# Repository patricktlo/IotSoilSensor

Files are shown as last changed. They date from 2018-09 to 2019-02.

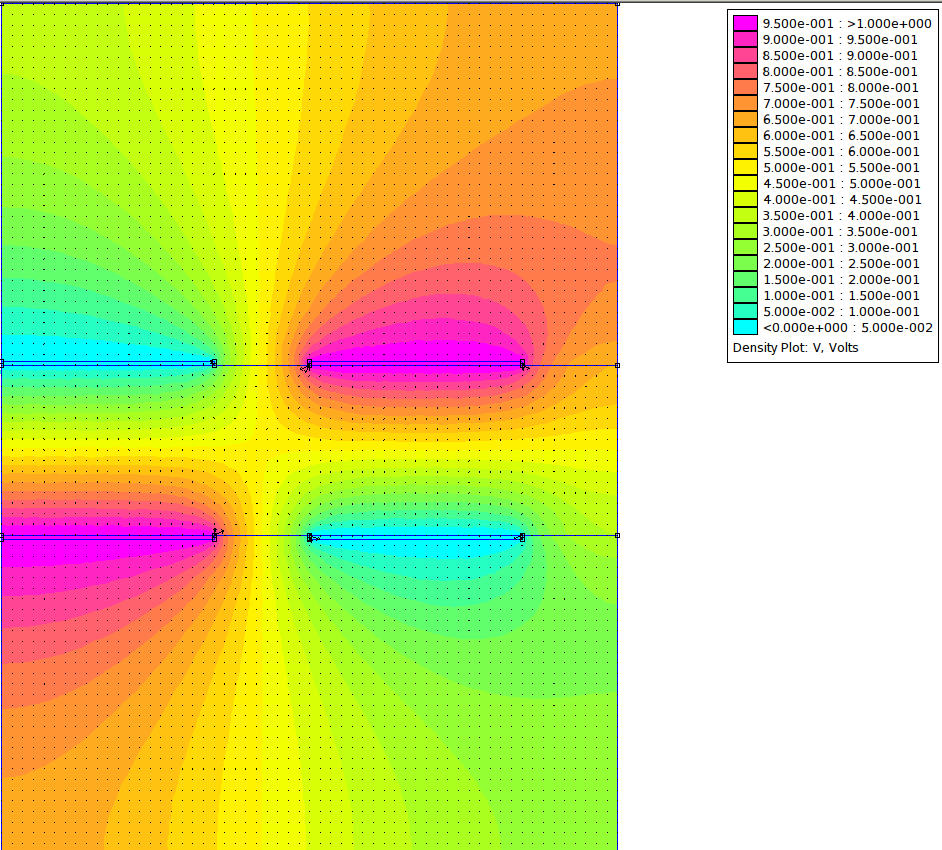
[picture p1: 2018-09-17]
1_Simulations/Moisture sensor/Simulation/FEMM Files/Images/w20_d09_air.png

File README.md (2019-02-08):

# IotSoilSensor

## This document is under construction!

This project aims to create a cheap LoRa-connected device to measure soil moisture using an embedded capacitive sensor. It also has a temperature sensor (NTC) and an air humidity sensor (HR202).

This project also contains a small simple gateway for LoRa using a LoRa module, a microcontroller and a Raspberry Pi.

## Soil moisture sensor

For the geometry of the sensor I chose a fringing field capacitive sensor because it is well documented and used in academic papers, it was also easy to design it in KiCAD, and easy to simulate in FEMM.

To measure the capacitance a simple RC circuit is used, where R is chosen to achieve a good resolution and measuring range. A comparator (which is inside the STM32L051 microcontroller) is connected to the output of the RC circuit, a simple resistive divider giving Vcc/2 is connected to the other pin of the comparator. 

A square wave is applied to the RC circuit, once the comparator changes state, the code of the MCU gets the value of the timer (the same one used for the square wave generations), with this value it is possible to measure the RC constant and hence the capacitive value. This circuit works quite well, before testing the capacitive sensor with it I tried it with capacitors and the results were really close to the nominal capacitive values ([data here](1_Simulations/Moisture%20sensor/Calibration/test_caps.ods))

### Soil moisture sensor calibration

The gravimetric analysis was used to calibrate our sensor, data can be found [here](1_Simulations/Moisture%20sensor/Calibration/test_gravi.ods). 

## Temperature sensor
The temperature sensor is an NTC thermistor because it's simple, cheap and doesn't depend on battery voltage (like DHT11 and others). The circuit is a simple resistor divider, where the value of the other resistor was chosen by finding the inflection point (using a double derivative, more information on the [HR202 sensor python notebook](1_Simulations/HR202/RH Simulation.ipynb), where I developed the math), you can find the math and some cool graphs on the [NTC sensor python notebook](1_Simulations/NTC/Simulation.ipynb). 

### Temperature sensor calibration
I used the beta-equation for the NTC, [look here for more info](1_Simulations/NTC/Simulation.ipynb).
      
The value of beta was given in the datasheet but I wanted to get a closer value so I calibrated it, see more details [in this spreadsheet](1_Simulations/NTC/NTC_calibration.ods).

## Air humidity sensor
The air humidity sensor was a tough one, it would've been pretty simple and straightforward to use a DHT11, but it would stop working when battery levels got to 3V (so pretty soon considering I'm using two AA batteries). So, I chose the HR202, there's not much about it but it's basically a resistive sensor, the RH value changes with temperature and you have to apply AC to it.

In order to provide AC voltage, I polarized the output at Vcc/2, using a resistor divider (look into the [LTSpice file](1_Simulations/HR202/hr202.asc) or the [KiCAD schematic](2_PCB/schematic.pdf) for more. The value of the resistor in this resistor divider is crucial because its value (or more precisely, the equivalent value of the two) define the output characteristics. To find the value of the resistors the inflex point was used (more info on the [HR202 sensor python notebook](1_Simulations/HR202/RH%20Simulation.ipynb)).

Also, just a quick note, since the input voltage is a square wave controlled by a timer, and we want to gather data from the ADC in sync with the square wave, it is needed to fire the ADC conversion with a timer as well.

### Air humidity calibration

It is difficult to calibrate this sensor, I found that the values in the datasheet weren't close to my results (although it could be some error in the circuit, I later found in another datasheet a somewhat different circuit which could work better). In order to get a fixed relative air humidity, I put the sensor inside a sealed container with a bottle cap of salt and water, that way after a few hours it gets to 75%.
I had an air humidity sensor so I could also use it as a reference. Even though the HR202 wasn't giving out exactly what was written on the datasheet, one could see the output voltage had a correlation with the humidity, so I got two known points, the 75% from the salt-water solution and the ambient RH from the other sensor, and fitted my sensor values to this line. It's far from perfect but it does give an idea of the RH.

## Battery

## LoRa

## STM32L051

## PCB

## Gateway
### Database

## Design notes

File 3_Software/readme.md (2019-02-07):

# Software

Two sub-folders are present here, one for the device itself, and one for the Gateway.

## Device

Code for the STM32L051 microcontroller is here, I used Atollic as my IDE (its free!) but you can use anything you like.

## Gateway

The gateway is separated into two components, a LoRa module connected to a STM32F103 MCU, and this one connected via UART to a rapsberry pi.

The sole purpose of the STM32 is to get LoRa messages, decode them and send them to the Raspberry Pi via UART, the RPi will then convert the ADC values into "real" values, and store them into an SQLite database. The RPi also has PHPLiteAdmin into it!

For future versions one might take the STM32 out of the gateway completely, but I was short in time!

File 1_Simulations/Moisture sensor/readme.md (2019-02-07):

# Moisture sensor simulation and calibration

I chose a fringing capacitance sensor because that's what was used in the articles I read and proved itself very efficient!

Here we have all files related to the simulation and calibration of the moisture sensor!

For simulation look at the simulation folder where you'll find LTSpice files for electrical simulations, FEMM files for estimating capacitance of the sensor (summary in the fringe_parameter_study.ods) and some timer-related calculations on the python notebook!

For calibration, test_caps.ods shows our circuit tested with capacitors, and it works extremely well!
On test_gravi.ods there's the gravimetric analysis I conducted in order to find out the equation which relates timer counts to humidity percentage.

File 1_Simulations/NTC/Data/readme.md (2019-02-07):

# Experimental values 

These are some tests I executed in order to estimate the noise.

The values are the ones given directly by the 12-bit ADC. If I remember correctly, sample time is 1 second.

ADC values are on the first column.

For the naming conventions:

avgX: means that the ADC used X-sample oversampling (executed at the hardware level).

capX: is the value of the capacitor connected to the ADC input.

gpio: means the power supply of the circuit was one GPIO pin of the microcontroller.

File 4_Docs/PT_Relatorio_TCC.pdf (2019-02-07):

MINISTERIO DA EDUCAÇ ´ | AÕ
UNIVERSIDADE FEDERAL DO PARANÁ

PATRICK THIERRY LORUSSO EL OMAIRI

DESENVOLVIMENTO DE UMA SOLUÇ AO INTERNET DAS COISAS ˜ PARA MEDIDA REMOTA DE TEMPERATURA, UMIDADE DO AR E DO SOLO COM BAIXO CUSTO E BAIXO CONSUMO DE ENERGIA

CURITIBA

2018

PATRICK THIERRY LORUSSO EL OMAIRI

DESENVOLVIMENTO DE UMA SOLUÇ AO INTERNET DAS COISAS ˜ PARA MEDIDA REMOTA DE TEMPERATURA, UMIDADE DO AR E DO SOLO COM BAIXO CUSTO E BAIXO CONSUMO DE ENERGIA

Trabalho | de | conclusao | de | curso ˜
apresentado | como | requisito | parcial
para a obtençao do grau de engenheiro ˜ eletricista, no programa de graduaçaõ em engenharia eletrica da Universidade ´ Federal do Parana. ´
Orientador: Prof. Dr. Marlio Jos ´ | e do Couto ´
Bonfim

CURITIBA

2018

AGRADECIMENTOS

Agradeço o Professor Marlio Jos ´ | e do Couto Bonfim pela orientaç ´ | ao durante todo esse ˜
trabalho que foi crucial para o sucesso do mesmo. Gostaria de agradecer tambem´ toda a minha família, minha namorada e meus amigos que tanto me apoiaram em todos os momentos.

RESUMO

Considerando a grande extensao territorial do Brasil e suas vastas lavouras, ˜ | é
imprescindível o uso de tecnologia na agricultura para aumento da produtividade. Dispositivos IoT e o avanço da agricultura 4.0 podem auxiliar imensamente nesta
tarefa. Neste contexto, esse trabalho propoe o desenvolvimento de uma soluç ˜ | ao de ˜
mediçao remota da temperatura, umidade relativa do ar e umidade do solo, com ˜
transmissao por uma rede ˜ | IoT LoRa de baixo consumo, com a intençao de obter uma ˜
soluçao com uma bateria de longa duraç ˜ | ao e baixo custo, com o uso de um ˜
microcontrolador STM32 e os sensores integrados na placa. O escopo deste trabalho
vai desde o desenvolvimento teorico desta soluç ´ | ao at ˜ | e um prot ´ | otipo para ser testado ´
em ambientes controlados. Este projeto sera open source e open hardware, para que
fazendeiros e pesquisadores da area possam utiliz ´ | a-lo livremente. | O prot ´ | otipo ´
desenvolvido tem uma autonomia de aproximadamente um ano e quatro meses com duas pilhas AA alcalinas, com um preço de 25 reais cada sensor. O prototipo mostra ´ que e poss ´ ível o desenvolvimento de um dispositivo como foi proposto.

Palavras Chave Agricultura 4.0, IoT, umidade do solo, LoRa.

ABSTRACT

Considering Brazil has a vast territory and a big part of it is being used for agriculture, it is crucial to use technology to augment productivity. IoT devices and agriculture 4.0 can help immensely in this task. In this context, this project seeks to develop a solution for the remote monitoring of temperature, soil moisture, and air humidity, using a LoRa network for transmission and an STM32L051 microcontroller aiming for a long battery life and low cost of the device. This project goes from the theory until the prototype, and it is open source and open hardware so that people can use this project in the future freely. The prototype has a battery life of about one year and four months, costing US$ 6.65 a piece. The prototype shows it’s possible to develop a product based on what was proposed.

Key-words: Agriculture 4.0, IoT, soil moisture, LoRa

LISTA DE FIGURAS

2.1 Curva característica de um resistor NTC. Fonte: O Autor (2018) | 11
2.2 Disposiçao dos condutores no sensor capacitivo. Fonte: DEAN et al. ˜
(2012) | | 13
2.3 Visao transversal dos condutores no sensor capacitivo. | Fonte: ˜
GOSWAMI, MONTAZER e SARMA (2018) | | 13
2.4 Divisor de tensao com um sensor. Fonte: O Autor (2018) | | 14 ˜

4.1 Esquematico do circuito de condicionamento feito no KiCAD. Fonte: O ´
Autor (2018) | | 17
4.2 Simulaçao da resposta do sensor aproximado com uma funç ˜ | ao de ˜
primeiro e terceiro grau e erros associados, a potencia dissipada no ˆ
NTC e o aumento da temperatura devido a essa potencia dissipada. ˆ
Fonte: O Autor (2018) | | 18
4.3 Fluxograma do funcionamento do sensor NTC. Fonte: O Autor(2018) . | 19
4.4 Simulaçao de campo el ˜ | etrico para sensor com ´ | w = 1, 5mm e d = 0, 3mm
com ar em volta do sensor. Fonte: O Autor (2018) | | 20
4.5 Layout do sensor no software KiCAD. Fonte: O Autor (2018) | | 21
4.6 Sensor feito a partir do desenho feito no KiCAD. Fonte: O Autor (2018) | 22
4.7 Circuito para aquisiçao do sinal do sensor de umidade do solo. Fonte: ˜
O Autor (2018) | 23
4.8 Circuito para simulaçao do sinal do sensor de umidade do solo. Fonte: ˜
O Autor (2018) | 24
4.9 Resultado da simulaçao do sinal do sensor de umidade do solo. Fonte: ˜
O Autor (2018) | 24
4.10 Fluxograma de funcionamento do sensor de umidade do solo. Fonte: O
Autor (2018) | | 26
4.11 Circuíto de condicionamento para o HR202. Fonte: O Autor(2018) . . . | 27
4.12 Ajuste de curva para a resposta do sensor HR202. Fonte: O Autor(2018) 27
4.13 Simulaçoes do sensor HR202. Fonte: O Autor(2018) | | 29 ˜
4.14 Simulaçao do sensor HR202 no LTSPice. Fonte: O Autor(2018) . . . . | 29 ˜
4.15 Fluxograma do funcionamento do HR202. Fonte: O Autor (2018) . . . . | 31
4.16 Esquematico do m ´ | odulo LoRa. Fonte: O Autor(2018) | | 32 ´
4.17 Mostra os spreading factors e o a quantidade de simbolo por bit de cada um e a sensibilidade necessaria no receptor de cada um. Fonte: ´
SEMTECH (2015) | 33
4.18 Relaciona a largura de banda e a velocidade de transmissao. Fonte ˜
SEMTECH (2015) | | 33
4.19 Conteudo do pacote de transmiss ´ | ao LoRa. Fonte: SEMTECH (2015). . | 34 ˜
4.20 Antena do modulo LoRa. Fonte: O Autor (2018) | | 35 ´
4.21 Diagrama da interaçao entre os m ˜ | odulos. Fonte: O Autor (2018) . . . . | 38 ´
4.22 Layout da PCB. Fonte: O Autor (2018) | | 39
4.23 Diagrama de conexoes do ˜ | gateway. Fonte: O Autor (2018) | | 39
5.1 Versoes de hardware anteriores do projeto. Fonte: O Autor (2018) . . . | 42 ˜
5.2 Ultima versao da placa, v1.2. Fonte: O Autor(2018) | | 42 ˜

5.3 Tensao de sa ˜ | ída na aquisiçao da temperatura. Fonte: O Autor (2018) . | 43 ˜
5.4 Tensao de sa ˜ | ída do sensor de umidade do solo, teste com o capacitor.
5.5 Demonstraçao do aumento da grandeza medida quando ˜ | e colocado ´
mais agua na terra onde se encontra o sensor. Fonte: O Autor (2018) . | 44 ´
5.6 Regressao linear das medidas obtidas para obtenç ˜ | ao da equaç ˜ | ao que ˜
relaciona capacitancia do sensor com umidade do solo. Fonte: O Autor ˆ
5.7 Tensao de sa ˜ | ída na aquisiçao da umidade relativa do ar. Fonte: O Autor ˜
5.8 Tensao de sa ˜ | ída quando o efeito da capacitancia ˆ | e mais forte. Fonte: O ´

5.9 Evoluçao da umidade relativa do ar dentro do recipiente com uma ˜
soluçao de sal saturada, mostra que o sensor est ˜ | a calibrado. Fonte: O ´

5.10 Valores coletados pelo sensor e enviados para o gateway via LoRa e

5.11 Interface phpLiteAdmin para o banco de dados SQLite. Fonte: O Autor

LISTA DE SIGLAS

IoT | Internet das coisas
MCU | Microcontrolador
RTC | Relogio tempo real ´
GPIO | Pino de entrada ou saída
PCB | Placa de circuito impresso
ADC | Conversor analogico-digital ´
TDR | Reflectometria no domínio do tempo

SUMARIO ´

RESUMO | 5
ABSTRACT | 6
1 INTRODUÇ AÕ | 9
1.1 Problematizaçao | | 9 ˜
2 FUNDAMENTAÇ AO TE ˜ | ORICA ´ | 11
2.4 Metodo da inflex ´ | ao para linearizaç ˜ | ao de sensores | | 13 ˜
2.5 Comunicaçao - LoRa | | 14 ˜
3 METODOLOGIA | 15
4 DESENVOLVIMENTO | 16
4.1.1 Concepçao | | 16 ˜
4.1.2 Simulaçao | | 16 ˜
4.1.3 Codigo e algoritmos | | 16 ´
4.2.1 Concepçao | | 17 ˜
4.2.2 Determinaçao dos par ˜ | ametros do sensor | | 20 ˆ
4.2.3 Simulaçao | | 23 ˜
4.2.4 Codigo e algoritmos | | 23 ´
4.3.1 Concepçao do sensor | | 25 ˜
4.3.2 Simulaçao do circuito | | 28 ˜
4.3.3 Codigo e algoritmos | | 28 ´
4.4 Modulo de comunicaçao LoRa | | 32 ˜
4.4.4 Implementaçao no c ˜ | odigo | | 34 ´

4.6.8 Botoes, LEDs e SWD | | 37 ˜
5 RESULTADOS | 41
5.1.1 Versoes de hardware da PCB | | 41 ˜
5.2.1 Calibraçao | | 41 ˜
5.3.1 Calibraçao | | 44 ˜
5.4.1 Calibraçao | | 46 ˜
5.5 Comunicaçao LoRa | | 48 ˜
6 CONCLUSAÕ | 51
BIBLIOGRAFIA | 52
A ESQUEMATICO COMPLETO DO CIRCUITO | 53 ´

CAPÍTULO 1

INTRODUÇ AÕ

### 1.1 Problematizaçaõ

Com a crescente demanda para uma produçao agr ˜ ícola mais eficiente, devido ao crescimento populacional em escala mundial e nacional, existe uma demanda muito
grande para metodos mais eficientes e ecol ´ | ogicos de agricultura. ´
Uma das maneiras de deixar o plantio mais eficiente, e medindo grandezas ´ no campo, como por exemplo a temperatura, a umidade do solo e do ar. O acompanhamento dessas grandezas em tempo real pode dar informaçoes essenciais ˜
para o fazendeiro. Por exemplo, tendo informaçoes sobre a umidade do solo, ser ˜ | á
possível saber quando sera o momento ideal para irrigar os campos. ´
Com varios sensores capazes de medir tais grandezas espalhados pela ´
fazenda, o fazendeiro seria capaz de obter informaçoes mais espec ˜ | íficas sobre
determinadas partes do campo, como a distribuiçao da temperatura, da umidade do ˜ solo e relativa do ar, e derivados destes.
Este projeto visa desenvolver um sensor capaz de medir a temperatura, a umidade relativa do ar e a umidade do solo, capaz de enviar essas informaçoes por ˜ uma rede IoT, mais especificamente, LoRa, tendo um consumo baixo e consequentemente uma grande autonomia.

### 1.2 Objetivos

### 1.2.1 Objetivo Geral

Desenvolver um dispositivo eletronico capaz de medir temperatura, umidade relativa ˆ do ar e do solo, e enviar os dados por uma rede IoT LoRa. Todos os sensores integrados junto do microcontrolador numa so placa de baixo custo e baixo consumo ´ de energia. O sensor de umidade do solo sera capacitivo para que ele tenha uma ´ boa performance e sera integrado dentro da placa de circuito impresso. ´

### 1.2.2 Objetivos Específicos

- Desenvolvimento do hardware.
- Simulaçao do hardware no LTSpice ou em ˜ | scripts Python.
- Desenvolvimento da uma placa de circuito impresso.
- Teste do hardware.
- Desenvolvimento do software embarcado para. microcontrolador STM32
- Implementaçao da comunicaç ˜ | ao via rede LoRa. ˜

### 1.3 Justificativa

As exportaçoes brasileiras ligadas ao agroneg ˜ | ocio chegam a 41,5% das vendas ´
externas totais no país, onde somente a soja e o principal produto exportado com ´
42,5% das exportaçoes nacionais do agroneg ˜ | ocio (FIESP, 2018). ´
Alem disso, a produç ´ | ao de carnes, outro setor muito importante para a ˜
exportaçao nacional, depende diretamente da agricultura uma vez que as raç ˜ | oes dos ˜
animais sao feitas com produtos provenientes da agricultura. ˜
Sendo entao a agricultura uma ˜ | area essencial para o desenvolvimento ´
economico e sustent ˆ | avel do Brasil, inovaç ´ | oes nessa ˜ | area tem um potencial enorme ´
para deixar mais eficiente o crescimento das plantas, diminuindo gastos com agua, ´ por exemplo.
Um dispositivo eletronico capaz de disponibilizar essas informaç ˆ | oes do campo ˜
para o fazendeiro pode ser essencial para o desenvolvimento do negocio, uma vez que ´
o fazendeiro podera monitorar seu plantio. E com o surgimento das redes ´ | IoT, se torna
mais viavel colocar v ´ | arios dispositivos desses, de baixo custo, espalhados pelo campo ´
para conseguir o maior numero de dados poss ´ | ível.

CAPÍTULO 2

FUNDAMENTAÇ AO TE ˜ ORICA ´

### 2.1 Sensor de temperatura

O sensor de temperatura escolhido (NTC) e um sensor do tipo termistor, onde sua ´ resistencia diminui exponencialmente conforme a temperatura aumenta, como ˆ
mostrado na equaçao 2.1 e na figura 2.1. Termistores NTC s ˜ | ao muito utilizados ˜
graças a seu custo reduzido e sua praticidade, mesmo nao sendo lineares e n ˜ | aõ
tendo uma faixa de temperatura grande quanto outros sensores de temperatura.

RNT C = R0 · e

B·(

1

T − 1 Tref
)
(2.1)

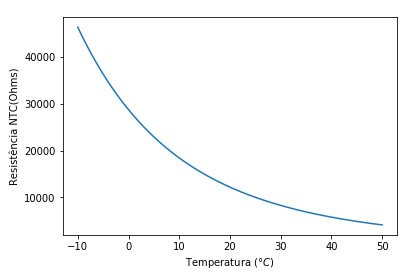
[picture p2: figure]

Figura 2.1: Curva característica de um resistor NTC. Fonte: O Autor (2018)

Mesmo com seu comportamento nao linear, ˜ | e poss ´ | ível linearizar o sensor
com um resistor de linearizaçao, fazendo um divisor de tens ˜ | ao entre o sensor e este ˜
resistor. O valor deste resistor pode ser calculado pelo metodo de inflex ´ | ao, como ˜ | é
explicado na seçao 2.4. ˜

### 2.2 Sensor de umidade relativa do ar

O sensor de umidade do ar escolhido, o HR202, e um sensor de umidade relativa ´
do ar, ele contem uma pel ´ | ícula organica que muda a resist ˆ | encia de acordo com a ˆ
umidade relativa do ar. Para este sensor e necess ´ | ario que seja aplicada uma tens ´ | aõ
alternada sobre ele para que ele nao perca suas propriedades, pois a pelicula dele ˜
e sens ´ | ível e pode mudar suas propriedades caso seja aplicada uma tensao cont ˜ | ínua
sobre o sensor.
Este sensor tambem´ | e exponencial, mas n ´ | ao constam no seu ˜ | datasheet os
parametros dessa equaç ˆ | ao, somente uma tabela onde se podem aproximar os valores. ˜

### 2.3 Sensor capacitivo de umidade do solo

Para medir a umidade do solo, uma das maneiras e fabricar um capacitor onde o ´
dieletrico seja o solo. Como a ´ | agua tem uma constante diel ´ | etrica muito maior que os ´
outros elementos, e poss ´ | ível estimar a quantidade de agua na amostra com base na ´
capacitancia. ˆ
Sensores capacitivos para medir umidade sao eficientes pois a permissividade ˜
da agua ´ | e muito maior que a do ar,v ´ | acuo ou solo, DEAN et al. (2012) cita algumas ´
aplicaçoes onde sensores capacitivos deste tipo s ˜ | ao adotados: ˜
- Umidade do solo
- Umidade em graos ˜
- Umidade em papel
- Detecçao de chuva ˜
- Sensor de proximidade
- Botoes capacitivos ˜
- Sensores biomedicos ´

Segundo DEAN et al. (2012) ,outras maneiras de medir a umidade do solo sao: ˜

- Propagaçao de ondas s ˜ | ísmicas
- Sonda de neutrons ˆ
- Sonda de raios gama
- Reflectometria no domínio do tempo (TDR)

A grande desvantagem de todas estas outras maneiras e a complexidade e o ´ custo, se pode fazer um sensor capacitivo numa placa de circuito impresso,
normalmente esses outros metodos necessitam de circuitos em uma frequ ´ | encia ˆ
muito maior, principalmente o mais usado entre eles, o TDR. A vantagem do TDR é que ele e mais preciso. ´
Ao contrario de um capacitor de placas paralelas, um sensor capacitivo deste ´ tipo e feito de maneira em que os condutores fiquem no mesmo plano, como na figura ´ 2.2, um corte transversal da estrutura pode ser visto na figura 2.3.
A largura de isolaçao, do condutor e de repetiç ˜ | oes afetam diretamente o ˜
desempenho do sensor. Quanto mais repetiçoes maior ser ˜ | a a capacit ´ | ancia, quanto ˆ
menor a isolaçao maior ser ˜ | a a capacit ´ | ancia, e quanto maior a largura do condutor ˆ
maior sera a penetraç ´ | ao do campo el ˜ | etrico no solo (MIZUGUCHI et al., 2015). ´
Varias configuraçoes diferentes, com variaç ˜ | oes na largura do condutor, da ˜
isolaçao e do uso da segunda camada s ˜ | ao propostas, GOSWAMI, MONTAZER e ˜
SARMA (2018) faz uma comparaçao entre v ˜ | arias configuraç ´ | oes propostas por outros ˜
artigos e demonstra vantagens do uso das duas camadas para aumentar a sensibilidade do sensor.
Este sensor deve ser calibrado para cada tipo de solo (GOSWAMI; MONTAZER; SARMA, 2018).

Figura 2.2: Disposiçao dos condutores no sensor capacitivo. Fonte: DEAN et al. (2012) ˜

Figura 2.3: Visao transversal dos condutores no sensor capacitivo. Fonte: GOSWAMI, ˜ MONTAZER e SARMA (2018)

2.4 Metodo da inflex ´ | ao para linearizaç ˜ | ao de sensores ˜
O ponto de inflexaõ e o ponto onde a segunda derivada ´ | e nula, logo, ´ | e o ponto onde ´
a curva muda de concava para convexa ou vice versa. Neste ponto, se uma reta for ˆ
traçada neste ponto com a inclinaçao (ou seja, a primeira derivada) deste ponto, ser ˜ | á
obtida uma funçao de linearizaç ˜ | ao que ter ˜ | a erros muito baixos, principalmente perto ´
do ponto.
Sensores como o NTC e o sensor de umidade relativa do ar tem características exponenciais, que podem ser representadas por uma equaçao como a ˜
2.2, logo e essencial poder lineariz ´ | a-las, onde ´ | X e o valor da grandeza medida, e ´ | B é
uma constante.

Rsensor(X) = R0 · e

| | (B/X−B/X0) | (2.2)
Quando e feito o circuito de aquisiç ´ | ao de um sensor exponencial como o NTC ˜
ou um sensor de umidade relativa do ar, e usada uma configuraç ´ | ao de divisor de ˜
tensao como esta da figura 2.4, e a tens ˜ | ao de sa ˜ | ída pode ser descrita pela equaçaõ
2.3.
| Vo = Vcc · | Rs Rs + Rsensor | (2.3)
Como esta equaçao muda o comportamento da sa ˜ | ída, ela muda tambem o ´
local do ponto de inflexao em funç ˜ | ao do resistor ˜ | Rs. Substituindo 2.2 em 2.3, derivando
duas vezes e isolando Rs obtemos a equaçao 2.4, onde ˜ | Xc e o valor da grandeza ´
medida no meio da faixa de interesse, e B e uma constante dada no ´ | datasheet.

Figura 2.4: Divisor de tensao com um sensor. Fonte: O Autor (2018) ˜

Rs = Rsensor(Xc) ·

B − 2 · Xc
B + 2 · Xc

(2.4)

Onde Rsensor e a resist ´ | encia do sensor no meio do faixa de interesse. Com ˆ
esta equaçaõ e poss ´ | ível mudar o ponto de inflexao para o meio da faixa de interesse, ˜
assim diminuindo o erro nos circuitos de mediçao. Al ˜ | em disso o divisor de tens ´ | ao ajuda ˜
a linearizar o sensor exponencial, como pode ser visto na figura 2.1 a resistencia de ˆ
um NTC, e na figura 4.2 este mesmo sensor onde foi aplicado o metodo da inflex ´ | aõ
para a linearizaçao. ˜

### 2.5 Comunicaçao - LoRa ˜

A rede LoRa e uma rede de baixo consumo, alto alcance e baixa taxa de transmiss ´ | ao. ˜
E uma rede muito utilizada por dispositivos ´ | IoT. LoRa utiliza um sistema de modulaçaõ
com chirps, uma senoide que muda de frequencia em funç ˆ | ao do tempo. ˜
E poss ´ | ível que o alcance de um gateway possa chegar ate 10 km, ´
dependendo do local, da potencia transmitida e do tipo de antena. Existem varias ˆ
frequencias de operaç ˆ | ao poss ˜ | íveis, dependendo da legislaçao local. | Algumas ˜
frequencias podem ser 433 MHz (EU), 868 MHz (EU) e 915 MHz (EUA). ˆ

CAPÍTULO 3

METODOLOGIA

A metodologia a ser seguida para desenvolver o projeto e a seguinte: ´
Começar por uma revisao bibliogr ˜ | afica, para ver o que j ´ | a foi feito. O foco nessa ´
parte e procurar artigos que implementaram, principalmente, a medida de umidade no ´ solo, pois e o mais importante para a planta. ´
Desenvolvimento do hardware, onde sera feita a escolha dos componentes, ´ dos circuitos de condicionamento dos sensores, do microcontrolador e do modulo de ´ transmissao LoRa. ˜
O sensor de temperatura e simulado no python, para escolher o resistor ideal ´ em serie e comparar alguns diferentes. ´
O sensor de umidade do ar tambem´ e simulado no python, para traçar a tens ´ | aõ
de saída e escolher os resistores ideais. Alem de ser simulado no LTSpice para tentar ´ modelar os componentes capacitivos deste sensor.
Para o sensor de umidade do solo, os parametros de largura e isolaç ˆ | ao, s ˜ | aõ
simulados no software FEMM. O sensor tambem´ | e simulado no LTSpice para ver sua ´
resposta ao circuito externo.
Uma vez a simulaçao feita, ˜ | e testado o hardware em testes de bancada. Com ´
o hardware funcionando, e feita a placa de circuito impresso no software KiCAD. ´
Com a PCB feita, e desenvolvido o software embarcado para STM32. O ´ firmware sera escrito em C, na IDE Atollic TrueSTUDIO. O software STM32CUBEMX ´
tambem ser ´ | a utilizado para geraç ´ | ao do c ˜ | odigo base. ´
Finalmente, sera desenvolvida a comunicaç ´ | ao via rede LoRa, com a ˜
construçao de um ˜ | gateway LoRa e com o codigo para esse ´ | gateway, onde e definida ´
a payload, e os parametros de rede. ˆ

CAPÍTULO 4

DESENVOLVIMENTO

Todos os arquivos do projeto estao dispon ˜ | íveis no GitHub pelo link
https://github.com/patricktlo/IotSoilSensor.

### 4.1 Sensor de temperatura

O sensor de temperatura escolhido foi o NTC, pois ele atende as demandas do projeto `
de baixo consumo, baixo custo e funciona independente da tensao de alimentaç ˜ | ao. ˜
Este ultimo item ´ | e crucial pois como existe uma queda de tens ´ | ao na bateria com sua ˜
descarga, e necess ´ | ario um sensor que trabalhe independente da tens ´ | ao. ˜

### 4.1.1 Concepçaõ

O circuito de condicionamento consiste em um divisor de tensao, sendo um sensor ˜
nao linear, como visto na seç ˜ | ao 2.1, necessita de um circuito de condicionamento ˜
para ser linearizado. Este circuito consiste simplesmente de um divisor de tensao, ˜ como mostrado na figura 4.1
O resistor de linearizaçao foi escolhido usando o m ˜ | | etodo da inflex ´ | ao, como ˜
explicado na seçao 2.4. O valor resultante foi ˜ | R = 7kΩ.

### 4.1.2 Simulaçaõ

Foram simulados, no python, a resposta do sensor real e aproximada por uma funçaõ
de grau um e tres, erros para esses dois casos tamb ˆ | em foram computados. Al ´ | em disso ´
foi simulada a potencia dissipada no NTC e o aumento de temperatura no sensor ˆ
devido a essa potencia dissipada, os resultados est ˆ | ao na figura 4.2. O erro com a ˜
funçao de primeiro grau ˜ | e menor (mais centrado) no caso onde ´ | R = 10kΩ, logo este
valor foi escolhido. O aquecimento do sensor e irris ´ | orio e pode ser ignorado. ´
A partir destas simulaçoes, se pode pegar os coeficientes da reta para se ˜
obter a temperatura, neste caso temos a equaçao 4.1, que relaciona sa ˜ | ída do ADC e
temperatura, onde a = 0, 00966 e a inclinaç ´ | ao da reta e ˜ | b = 0, 25 e a interseç ´ | ao da reta ˜
em y.

T =

| ADC/4095 − b
a

(4.1)

### 4.1.3 Codigo e algoritmos ´

A energia provida para a ponte resistiva vem de um pino GPIO, para poder economizar
energia e desligar quando mediçoes n ˜ | ao estarem sendo feitas. ˜
A obtençao da temperatura a partir das medidas do divisor de tens ˜ | | | aõ e feito ´
com a equaçao 4.1 para uma aproximaç ˜ | ao de primeiro grau, ou 4.2 para uma ˜

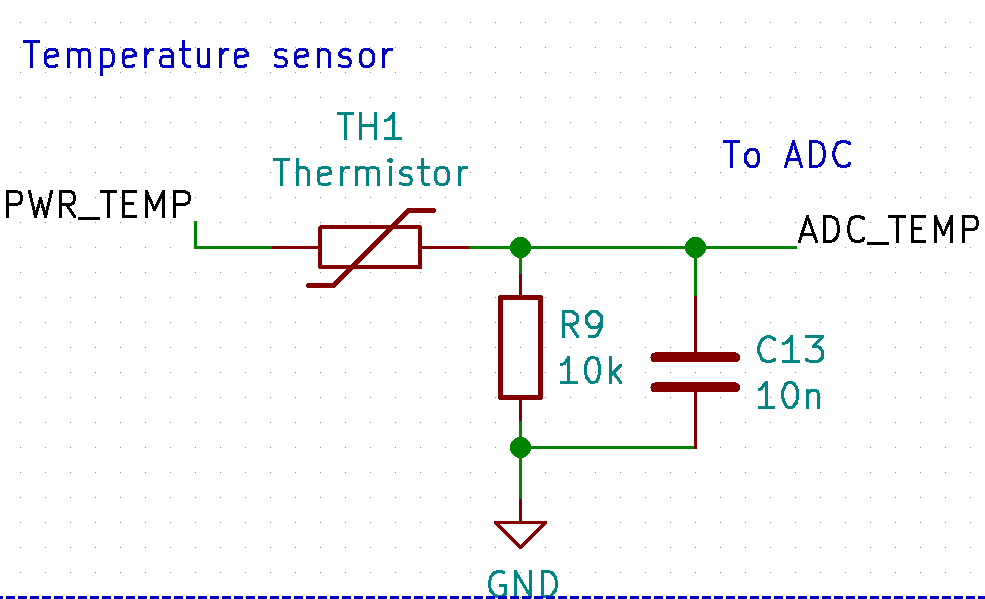
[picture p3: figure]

Figura 4.1: Esquematico do circuito de condicionamento feito no KiCAD. Fonte: O ´ Autor (2018)

aproximaçao de terceiro grau, na segunda, onde seus coeficientes s ˜ | aõ
[a3, a2, a1, a0] = [174.324, −220.791, 193.122, −38.177]. Porem isso depende de cada ´
sensor e deve ser feito apos a calibraç ´ | ao do mesmo. ˜

T = a3 · V

3
out + a2 · V

2
out + a1 · Vout + a0 | (4.2)
O fluxograma da figura 4.3 representa o funcionamento do codigo. O programa ´
começa configurando o ADC, ligando o ADC e ligando a alimentaçao do NTC, ent ˜ | aõ
sao feitas 16 amostras e a m ˜ | edia entre elas (esta parte ´ | e feita por hardware), o NTC e ´
o ADC sao desligados, e o valor ˜ | e retornado. ´
Como a informaçao de temperatura n ˜ | aõ e de interesse do sensor e sim do ´
gateway, que mostra a informaçao ao usu ˜ | ario, o sensor vai transmitir a informaç ´ | ao do ˜
ADC bruta ao gateway e este ira fazer os c ´ | alculos para a temperatura, que ´ | e aplicar a ´
equaçao 4.1 ou 4.2 ˜ | a informaç ` | ao recebida. ˜

### 4.2 Sensor de umidade do solo capacitivo

### 4.2.1 Concepçaõ

Para medir a umidade do solo, foi escolhido um sensor capacitivo, que muda a
capacitancia de acordo com a quantidade de ˆ | agua no solo. Para isso, foi feito o layout ´
de um sensor capacitivo em uma PCB, onde o dieletrico ´ | e o solo. Como a ´ | agua tem ´
uma permissividade eletrica em torno de 80 vezes maior do que a do solo, a ´
capacitancia aumenta com a quantidade de ˆ | agua no solo. ´
Mais informaçoes sobre o design est ˜ | ao presentes na seç ˜ | ao 2.3. ˜

(a) Simulaçao com ˜ | R = 7kΩ
(b) Simulaçao com ˜ | R = 10kΩ
Figura 4.2: Simulaçao da resposta do sensor aproximado com uma funç ˜ | ao de primeiro ˜
e terceiro grau e erros associados, a potencia dissipada no NTC e o aumento da ˆ temperatura devido a essa potencia dissipada. Fonte: O Autor (2018) ˆ

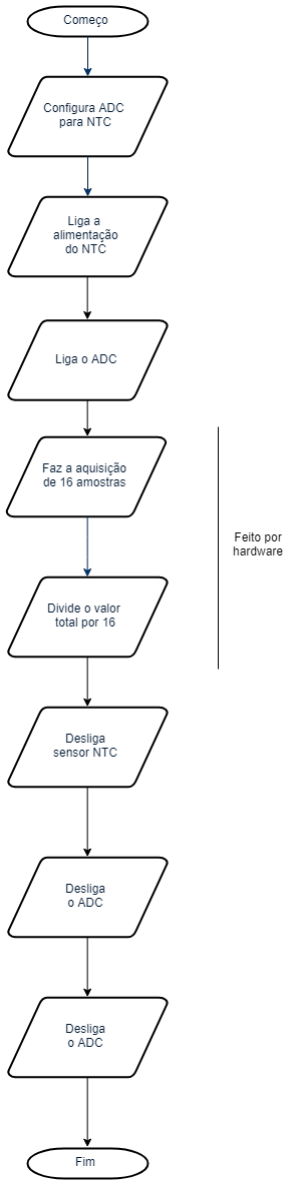
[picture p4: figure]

Figura 4.3: Fluxograma do funcionamento do sensor NTC. Fonte: O Autor(2018)

4.2.2 Determinaçao dos par ˜ | ametros do sensor ˆ
Para escolher os parametros de largura do condutor e do isolador ( ˆ | w, d,
respectivamente) sera usado o software FEMM para simular o efeito desses ´
parametros na capacit ˆ | ancia e na penetraç ˆ | ao do campo el ˜ | etrico. ´
As simulaçoes foram feitas considerando uma PCB de ˜ | 1, 6mm de espessura
de fenolite, com cobre de espessura de 36µm.
Os parametros escolhidos no final foram os da figura 4.4, com ˆ | d = 0, 3mm
pois e um valor fact ´ | ível para uma PCB caseira, e w = 1, 5mm pois oferece uma boa
penetraçao do campo el ˜ | etrico enquanto possibilita a repetiç ´ | ao de v ˜ | arios conjuntos ´
como esse para aumentar a sensibilidade do sensor.

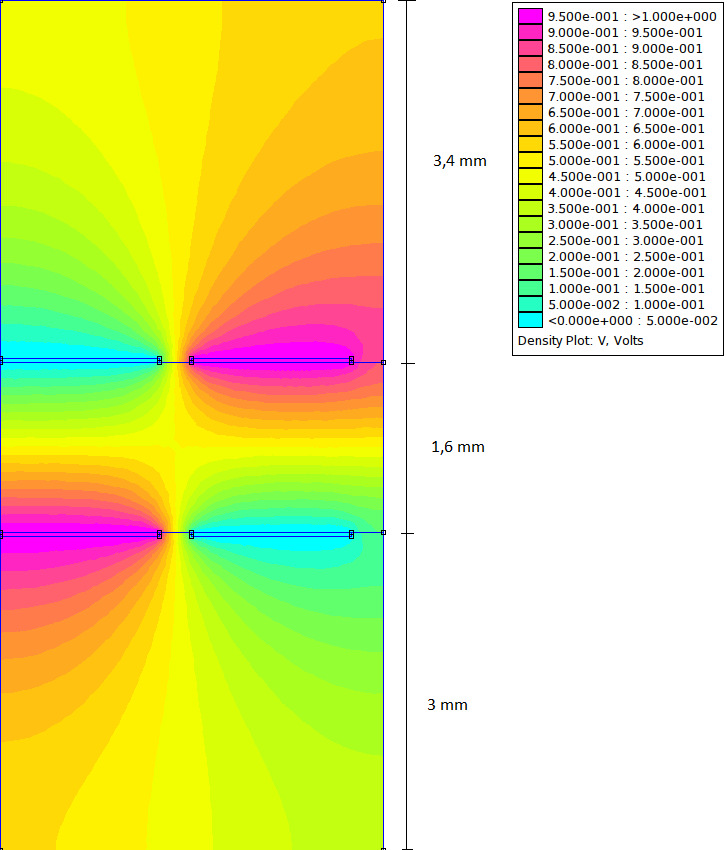
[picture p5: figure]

Figura 4.4: Simulaçao de campo el ˜ | etrico para sensor com ´ | w = 1, 5mm e d = 0, 3mm
com ar em volta do sensor. Fonte: O Autor (2018)

Na tabela 4.1 se encontram diversas configuraçoes diferentes com os valores ˜
de capacitancia para solo totalmente seco, solo parcialmente molhado e ˆ | | agua para ´
uma PCB de 47 mm.
Segundo a simulaçao, a capacit ˜ | ancia varia entre ˆ | 57pF até 740pF, segunda a
tabela 4.1, na coluna onde w = 1, 5mm e d = 0, 3mm.

Tabela 4.1: Valores de capacitancia para diversas configuraç ˆ | oes testadas ˜
Dimensoes ˜ | w (mm) | 0.50 | 0.50 | 2.00 | 1.50 | 1.50
| d (mm) | 0.50 | 0.30 | 0.90 | 0.50 | 0.30
C (pf)/par | Seco | 2.80 | 3.17 | 5.42 | 4.84 | 5.23
| Terra 30% | 15.89 | 18.92 | 20.65 | 22.26 | 25.77
| Molhado | 42.37 | 50.74 | 51.20 | 57.51 | 67.34
Numero de pares | | 23.00 | 29.00 | 8.00 | 11.00 | 13.00
Ctotal (pF) | Seco | 64.40 | 72.91 | 157.18 | 38.72 | 57.53
| Terra 30% | 365.47 | 435.16 | 598.85 | 178.08 | 283.47
| Molhado | 974.51 | 1167.02 | 1484.80 | 460.08 | 740.74

Desenvolvimento do sensor

O sensor desenvolvido foi desenhado como um componente no software KiCAD, o resultado esta representado na figura 4.5. ´

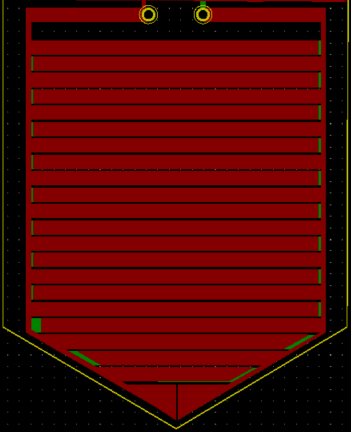
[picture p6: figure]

Figura 4.5: Layout do sensor no software KiCAD. Fonte: O Autor (2018)

O sensor foi produzido com o metodo fotossens ´ | ível, o resultado pode ser
visto na figura 4.6. Na placa final o sensor pode ser acoplado ao resto do circuito ou
separado, neste caso ele esta separado mas na figura 5.2 a placa est ´ | a com o sensor ´
acoplado.

Circuito de condicionamento

Para medir a capacitancia do sensor, ser ˆ | a usado um simples circuito RC, com um ´
comparador interno ao microcontrolador que ira mandar um sinal quando o valor de ´

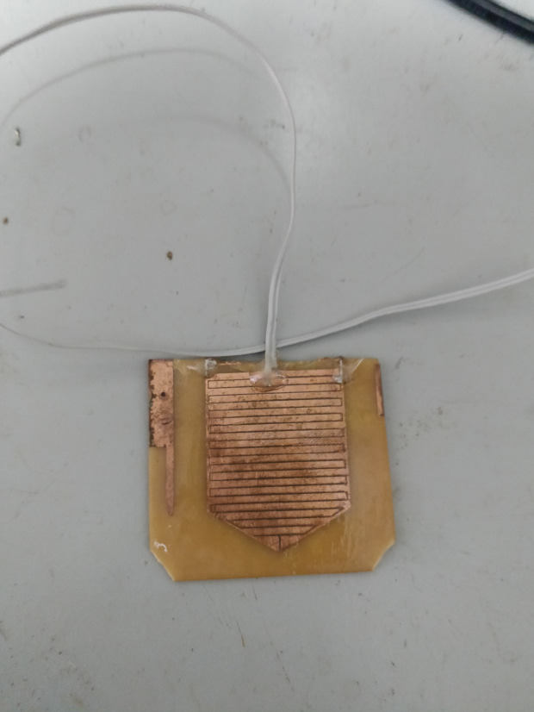
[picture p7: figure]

Figura 4.6: Sensor feito a partir do desenho feito no KiCAD. Fonte: O Autor (2018)

saída do RC for maior que um valor definido por uma ponte resistiva na entrada negativa do comparador.
O circuito de mediçaõ e apresentado na figura 4.7. ´
A escolha do resistor em serie, da frequencia da onda e da ponte resistiva se ˆ baseiam nos valores simulados de capacitancia. ˆ
Consideraremos como valor mínimo e maximo da capacit ´ | ancia do sensor ˆ
50pF e 2nF respectivamente, para ter uma margem de segurança. Considerando que o timer do MCU possua um valor de contador de 16 bits, e considerando que o
circuito se carrega em 5 · R · Cs, o valor maximo, em contagens do ´ | timer pode ser
representado pela equaçao 4.3. Valores adequados para a resist ˜ | encia e a frequ ˆ | encia ˆ
para obter a maior resoluçao seriam ˜ | R = 220kΩ e f = 8MHz, que sao valores usuais ˜
e faceis de obter. ´
| 5 · R · Cmax · f < 2
| 16 | (4.3)
Alem disso o valor de ´ | auto reload do timer, isto e, o valor que o ´ | timer irá
recomeçar a contagem, sera de ´ | 60k, que obedece a inequaçao 4.3, e corresponde ˜ | à
uma onda quadrada de período T = 15ms.
Para a ponte resistiva que ira delimitar o valor na entrada negativa do ´ comparador, e conveniente escolher um valor onde tanto a carga quanto descarga do ´ circuito RC tenham a mesma constante de tempo, usando a equaçao da carga e ˜ descarga de um circuito RC, nas equaçoes 4.4 e 4.5, e igualando as duas se pode ˜ obter t = RC · (ln(2) − ln(1)) = 0, 693 · RC, e para esse t a tensao normalizada pode ˜
ser obtida a partir de qualquer uma das duas equaçoes e corresponde ˜ | à
V (t)/V0 = 0, 5, logo uma ponte resistiva com dois resistores iguais e desejada, os ´ valores escolhidos saõ 22kΩ.
| V (t) = V0 · (1 − e
| t/RC) | (4.4)
| V (t) = V0 · e
| t/RC | (4.5)

Figura 4.7: Circuito para aquisiçao do sinal do sensor de umidade do solo. Fonte: O ˜ Autor (2018)

### 4.2.3 Simulaçaõ

O circuito foi simulado no LTSpice, com o circuito presente na figura 4.8. O resultado e dado na figura 4.9. ´

### 4.2.4 Codigo e algoritmos ´

O MCU liga o comparador e a onda quadrada, com período 15ms, espera ate o ´ comparador mudar de estado e grava o tempo do timer. Com esse tempo, e sabendo
em qual tensao o comparador foi acionado, basta usar a equaç ˜ | ao 4.4 ou 4.5, de ˜
carga ou descarga de um circuito RC para medir a constante de tempo τ = RC do circuito RC.
E a partir disso a equaçao para determinar a capacit ˜ | ancia do sensor ˆ | e dada ´
na equaçao 4.6, esta parte ser ˜ | a feita no ´ | gateway, o sensor ira transmitir somente o ´
valor de t.

C =

−t
ln(V (t)/V0) · R

(4.6)

Onde t e medido logo que o comparador manda a informaç ´ | ao, ˜ | V (t)/V0 = 0, 5
e R = 220kΩ sao definidos pela ponte resistiva na entrada negativa do comparador e ˜ pelo resistor em serie, como pode ser visto na figura 4.7. ´
A informaçao da umidade do solo pode ser tirada a partir da capacit ˜ | | | ancia ˆ
medida. A equaçao da umidade do solo ˜ | e dada na equaç ´ | ao 4.7, onde ˜ | Mmolhado e a ´
massa da terra molhada, Mseco e a massa da terra seca e ´ | Mrecipiente e a massa do ´
recipiente onde se encontra a amostra. Normalmente, o sensor exposto ao ar deve resultar numa umidade de 0% enquanto o sensor imerso totalmente em agua deve ´ indicar uma umidade do solo de 100 %.

MS = 100 ·

| Mmolhado − Mseco
| Mseco − Mrecipiente | | (4.7)

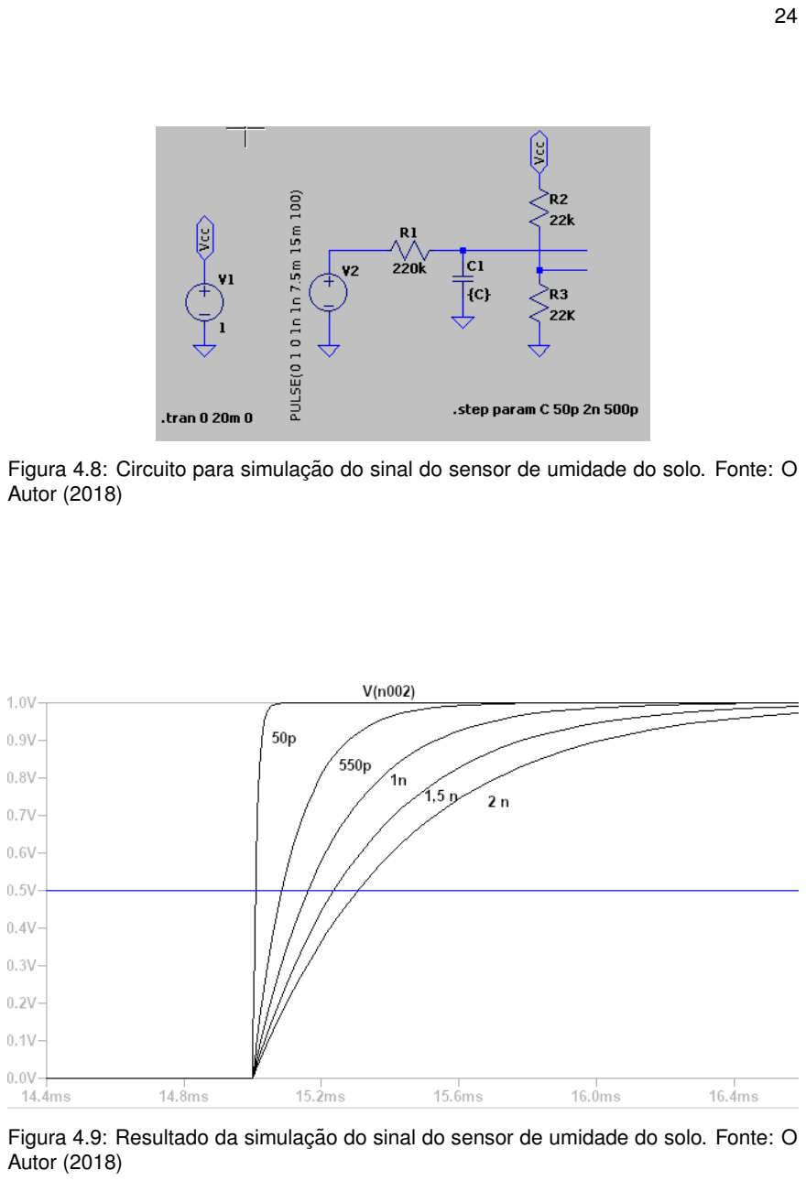
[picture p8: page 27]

Figura 4.8: Circuito para simulaçao do sinal do sensor de umidade do solo. Fonte: O ˜ Autor (2018)

Figura 4.9: Resultado da simulaçao do sinal do sensor de umidade do solo. Fonte: O ˜ Autor (2018)

O funcionamento pode ser resumido no fluxograma da figura 4.10. O programa começa ligando a ponte resistiva (do comparador), o comparador e a onda quadrada (e consequentemente seu timer), entao o programa checa em loop se o ˜ estado do comparador mudou, quando for o caso, e anotado o valor do timer (que ´
sera usado futuramente para c ´ | alculo da capacit ´ | ancia). Isto ˆ | e repetido oito vezes para ´
pegar varias medidas, e ent ´ | aõ e desligado todos os componentes, ´ | e feita a m ´ | edia ´
dos oito valores e o valor e retornado. ´

### 4.3 Sensor de umidade relativa do ar

O sensor de umidade do ar escolhido e o HR202, pois este atende ´ | as necessidades `
do projeto de custo, precisao e n ˜ | ao depende da tens ˜ | ao da bateria, j ˜ | a que ´ | e um circuito ´
resistivo.
O sensor contem condutores imersos em uma camada de uma subst ´ | ancia que ˆ
muda a resistencia com a umidade relativa do ar. ˆ

### 4.3.1 Concepçao do sensor ˜

Uma particularidade deste sensor e a necessidade da aplicaç ´ | ao de uma tens ˜ | aõ
alternada sobre ele, para nao mudar as propriedades do sensor. ˜
Para fazer isto, o sensor foi ligado como na figura 4.11, ligando o sensor entre umaa saída com uma onda quadrada e uma ponte resistiva que polariza a saída em Vcc/2.
Este sensor possui uma característica exponencial, porem, diferente do NTC ´
o datasheet nao cont ˜ | em nenhuma equaç ´ | ao, s ˜ | o uma tabela de valores que variam ´
com a temperatura. Alem disto este sensor possui uma caracter ´ | ística capacitiva, seu
modelo eletrico ´ | e um resistor com um capacitor em paralelo (NENOV; IVANOV, 2007). ´
A frequencia escolhida para a onda quadrada ˆ | e de ´ | 3, 9Hz, com um período de 256ms,
para evitar que os efeitos capacitivos interfiram nas medidas.
Para linearizar o circuito e utilizado o m ´ | etodo da inflex ´ | ao, a temperatura ˜ | é
fixada em 25◦C , e usada a funçaõ curve fit da biblioteca scipy para aproximar os
dados da tabela para uma funçao de forma da equaç ˜ | ao 4.8, resultando na adequaç ˜ | aõ
mostrada na figura 4.12.
| RHR202 = R0 · exp(

β
RH

−

β
| | RH0
) | (4.8)
A equaçao da resist ˜ | encia equivalente visto do ADC, do esquem ˆ | atico ´
representado na figura 4.11, e representada na equaç ´ | ao 4.9, onde ˜ | Rs sao as ˜
resistencias que comp ˆ | oem a ponte resistiva da sa ˜ | ída (R9 e R10 da figura 4.11) e Rrh
e o valor do sensor. ´

Req =

Rs · Rrh
Rs + 2 · Rrh

(4.9)

O metodo da inflex ´ | ao, como explicado na seç ˜ | ao 2.4, ˜ | e aplicado substituindo ´
Rrh na equaçao 4.9 pela equaç ˜ | ao 4.8, derivando duas vezes, igualando a zero e ˜
isolando Rs na equaçao, onde se chega no valor ˜ | Rs = 39kΩ, foi escolhido entaõ
Rs = 47kΩ por ser um valor mais comum.

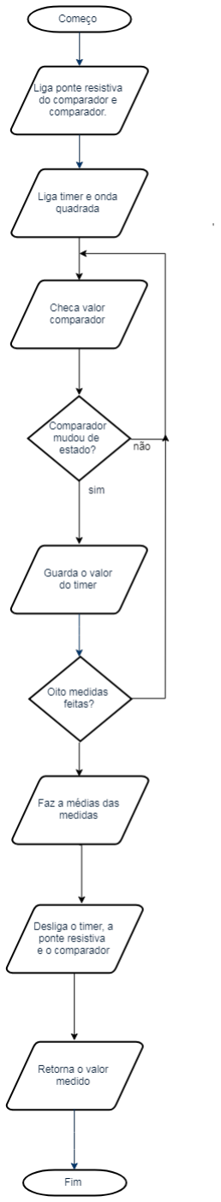
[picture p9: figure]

Figura 4.10: Fluxograma de funcionamento do sensor de umidade do solo. Fonte: O Autor (2018)

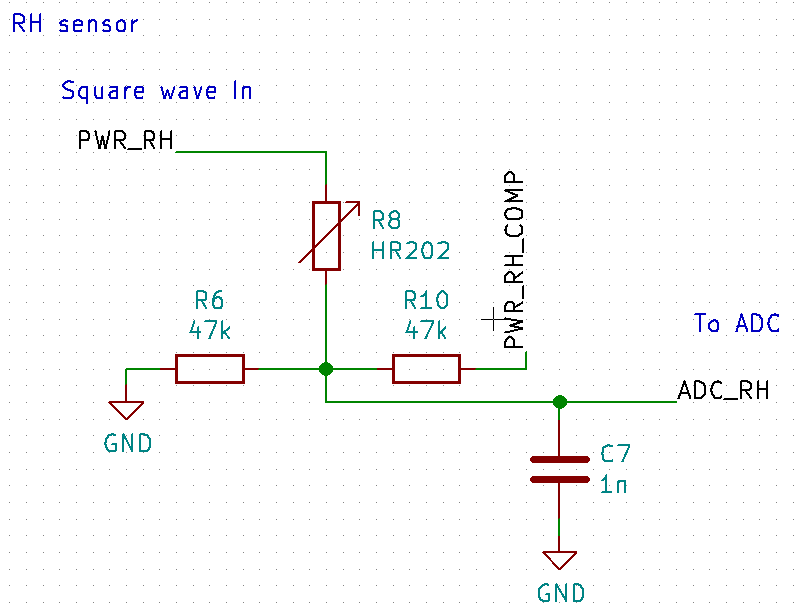
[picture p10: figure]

Figura 4.11: Circuíto de condicionamento para o HR202. Fonte: O Autor(2018)

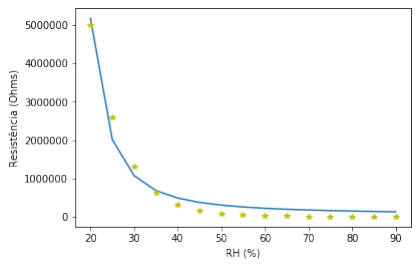
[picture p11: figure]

Figura 4.12: Ajuste de curva para a resposta do sensor HR202. Fonte: O Autor(2018)

O circuito final fica entao como na figura 4.11, com a adiç ˜ | ao de um capacitor ˜
em paralelo com a entrada do ADC que possui a funçao de filtro passa-baixas e ˜ tambem para suprir cargas mais rapidamente ao capacitor de amostragem interno ao ´ conversor ADC.
Para calcular a capacitancia m ˆ | axima deste capacitor, ´ | e necess ´ | ario calcular a ´
resistencia equivalente m ˆ | axima dos dois resistores de linearizaç ´ | ao e do sensor, que ˜ | é
dada pela equaçao 4.9 quando ˜ | Rrh esta no seu valor m ´ | aximo, segundo seu ´ | datasheet
o valor maximo ´ | e pr ´ | oximo de ´ | 13MΩ, logo podemos considerar que e um circuito aberto ´
e temos como resistencia equivalente o paralelo entre as duas resist ˆ | encias ˆ | Rs do
divisor de tensao, logo, ˜ | Rpmax = Rs/2, e neste caso Rpmax = 23, 5kΩ.
Dado que a frequencia ˆ | e de ´ | 3, 9Hz, o período em que o sinal fica em cada
sinal logico ´ | é 128ms, para calcular o capacitor, consideramos que e necess ´ | ario ´ | 100ms
para que a tensao fique est ˜ | avel e resta ´ | 28ms para a aquisiçao do ADC. Com isso o ˜
valor da capacitancia ˆ | e limitada pela equaç ´ | ao 4.10. ˜
10 · R · C < TADC/2 | (4.10)
Inserindo os valores na equaçao 4.10, temos que ˜ | C < 59nF, o valor escolhido
é C = 4, 7nF, para manter um valor alto mas que nao interfira muito. ˜

### 4.3.2 Simulaçao do circuito ˜

Este circuito foi simulado em um script python e no LTSpice.
No script python foi simulada a tensao de sa ˜ | ída do circuito e a sensibilidade
do circuito, os resultados podem ser vistos, para diversos valores de Rs na figura 4.13. No software LTSpice para simular a resposta do circuito a uma onde quadrada. `
Na figura 4.14 consta a resposta do circuito simulado, com uma frequencia de ˆ | 3, 9Hz.
E interessante notar o efeito capacitivo do sensor quando ocorre a mudança de estado ´ da onda quadrada, principalmente para os altos valores de resistencia (baixos valores ˆ de umidade relativa do ar).

### 4.3.3 Codigo e algoritmos ´

Para filtrar o sinal, sera feita a amostragem em dois momentos, quando a onda ´ quadrada estiver em Vcc o valor do ADC sera armazenado em adchigh e quando
estiver em 0V sera armazenado em adclow. Em cada valor obtido existira tamb ´ | em´
uma sobre-amostragem, feita por hardware, com 16 amostras. | Alem desta ´
sobre-amostragem, e feita uma outra utilizando 4 ondas em tempos diferentes, duas ´ positivas e duas negativas.
A aquisiçao das amostras sera feita ˜ | 100ms apos a mudança de estado da ´
onda quadrada, para nao tomar em conta os efeitos produzidos pela capacit ˜ | ancia do ˆ
sensor. Para garantir que o ADC e o timer estejam defasados corretamente, e usado ´ um outro timer, deslocado em 100ms do timer do da onda quadrada, que ativa o ADC nos momentos certos.
O funcionamento do codigo ´ e resumido no fluxograma representado na figura ´
4.15. O programa começa configurando o ADC, ligando o divisor resistivo do circuito, ligando o ADC, iniciando os timers (tanto da onda quadrada quando o do ADC), e entaõ
a cada interrupçao do ADC ˜ | e guardado o seu valor, e ao final de quatro s ´ | ao feitas duas ˜

Figura 4.13: Simulaçoes do sensor HR202. Fonte: O Autor(2018) ˜

Figura 4.14: Simulaçao do sensor HR202 no LTSPice. Fonte: O Autor(2018) ˜

media entre elas (uma para quando a onda quadrada est ´ | a em estado l ´ | ogico 1, e uma ´
para estado logico 0), e todos os componentes s ´ | | ao desligados. ˜
Dado que o tratamento do sinal e complexo, a placa manda a informaç ´ | aõ
bruta para o gateway, que analisa esta informaçao bruta e converte em umidade do ar ˜ relativa.

Decodificaçao dos valores no gateway ˜

Com as aquisiçoes recebidas, ˜ | e subtra ´ | ído destes valores a metade da resoluçao do ˜
ADC (equaçoes 4.11 e 4.12), e ent ˜ | aõ e feita a m ´ | edia entre os dois na equaç ´ | ao 4.13, ˜
para se obter uma medida que toma em conta os dois casos. Esta parte e feita no ´ gateway.
| M1 = adchigh − 2 | 12−1
2

12 − 1

(4.11)

| M2 = adclow − 2 | 12−1
2

12 − 1

(4.12)

Vm/Vcc = M1 − M2 | (4.13)
A equaçao que relaciona esta sa ˜ | | ída Vm aos valores dos resistores e dada pela ´
equaçao 4.14. ˜
| Vm = Vout| | Vsq=1 − Vout|
Vsq=0 | (4.14)
Aplicando analise de circuitos, desenvolvendo a equaç ´ | ao 4.14 e isolando ˜ | RRH,
chegamos a equaçaõ
| RRH = RS · | 1 − Vm 2Vm
(4.15)
Uma vez com o valor de RRH, e necess ´ | ario interpolar a tabela 4.2 para obter ´
o resultado correto.

Tabela 4.2: Valores de umidade do ar para diferentes resistencias e temperaturas. ˆ Fonte: ELECROW ()

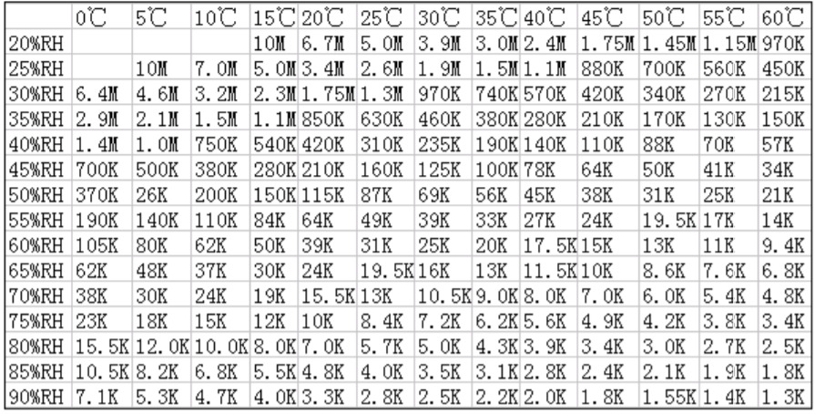
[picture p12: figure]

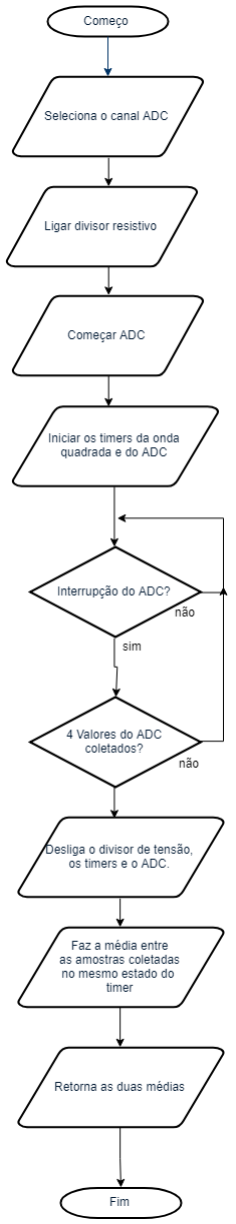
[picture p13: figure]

Figura 4.15: Fluxograma do funcionamento do HR202. Fonte: O Autor (2018)

A interpolaçao foi feita no python com a funç ˜ | | aõ interp1d da biblioteca scipy, a
temperatura considerada no calculo ´ | e arredondada para os ´ | 5

◦C mais proximos. Esta ´
funçao faz a interpolaç ˜ | ao linear dos valores. ˜

### 4.4 Modulo de comunicaçao LoRa ˜

O modulo escolhido ´ | e o RA-01, que tem como chip o SX1278 e transmite numa ´
frequencia de ˆ | 433MHz.

### 4.4.1 Circuito

O modulo LoRa RA-01 foi conectado com SPI, como mostra na figura 4.16 ´

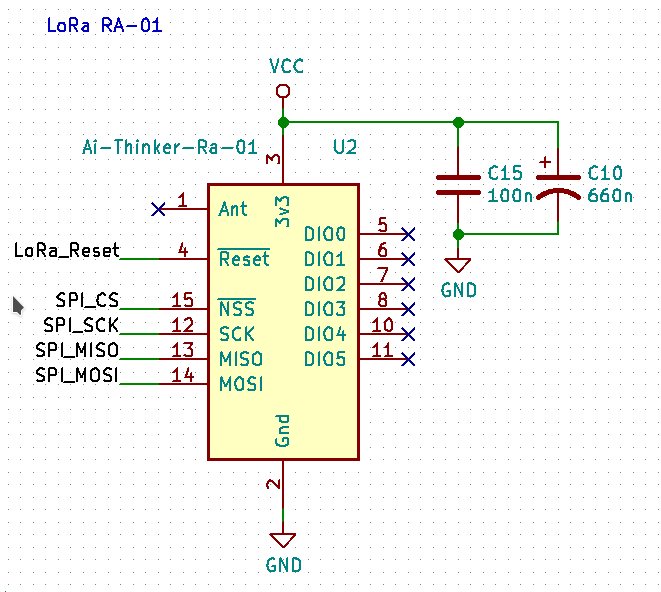
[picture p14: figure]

Figura 4.16: Esquematico do m ´ | odulo LoRa. Fonte: O Autor(2018) ´

Existem alguns parametros que podem ser mudados com o intuito de ajustar ˆ a transmissao para atender as necessidades do projeto. ˜

Spreading Factor

O spreading factor e um par ´ | ametro que dita quantos s ˆ | ímbolos sao mandados para ˜
cada bit de informaçao. Quanto mais s ˜ | ímbolos, mais sensibilidade ao ruido tera o ´
receptor, menor sera a velocidade da transmissao e maior ser ˜ | a o consumo de energia, ´
como mostra a figura 4.17.
Como neste projeto naõ e necess ´ | ario uma alta taxa de transmiss ´ | ao e se preza ˜
alcance sobre isso, logo o spreading factor escolhido e 12. Mesmo com um consumo ´
de energia mais alto, ele continua dentro do aceitavel como ser ´ | a discutido na seç ´ | aõ
5.6.

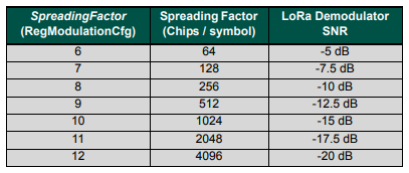
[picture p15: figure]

Figura 4.17: Mostra os spreading factors e o a quantidade de simbolo por bit de cada um e a sensibilidade necessaria no receptor de cada um. Fonte: SEMTECH (2015) ´

Figura 4.18: Relaciona a largura de banda e a velocidade de transmissao. Fonte ˜ SEMTECH (2015).

Largura de banda

A largura de banda influencia na velocidade de transmissao, como pode ser visto na ˜ figura 4.18.
Para diminuir o tempo de transmissao, ser ˜ a utilizada uma largura de banda de ´ 125kHz, uma largura de banda mais alta diminui tambem as chances de assincronia ´ entre o receptor e o transmissor, causado por erros no oscilador.

Header

Existem dois tipos de headers disponíveis, o implícito e o explicito. No explicito o
tamanho da payload, e a presença de um CRC sao especificados, no impl ˜ | ícito, para
diminuir a informaçao para transmitir, o tamanho da ˜ | payload e a presença de um
CRC sao definidos no transmissor e receptor. Como se trata de um prot ˜ | otipo e as ´
informaçoes podem mudar, por ora foi escolhido um ˜ | header explicito, num produto
final seria ideal utilizar um header implícito.

### 4.4.2 Corpo de dados

O corpo de dados (payload e composto da informaç ´ | ao dos tr ˜ | es sensores, estas ˆ
informaçoes est ˜ | ao na tabela 4.3. Estes s ˜ | ao s ˜ | o os dados da transmiss ´ | ao, na figura ˜
4.19 se encontram todos os dados que serao transmitidos no pacote. | Ser ˜ | aõ
transmitidos 10 bytes de dados.

Tabela 4.3: Tamanho dos dados de cada sensor. Fonte: O Autor (2018)

Sensor | Tamanho do dado (bits)
NTC | 12
MS | 16
HR202 | 24
Numero da mensagem ´ | 14
Numero do sensor ´ | 10
Total | 76

Desta maneira, o sistema suportaria 1024 sensores, e cada um teria um
numero de mensagem ´ | unico por aproximadamente dois anos. ´

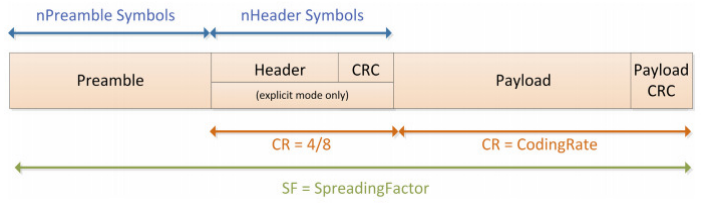
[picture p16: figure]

Figura 4.19: Conteudo do pacote de transmiss ´ | ao LoRa. Fonte: SEMTECH (2015). ˜

### 4.4.3 Antena

As antenas utilizadas, tanto para o gateway quando para o sensor, sao as fornecidas ˜ junto com o modulo, como pode ser visto na figura 4.20. Principalmente para o ´ gateway, seria interessante mudar de antena para melhorar o alcance. O tipo da antena a ser usada depende muito do uso específico e do local onde sera instalada a ´ antena dentro da fazenda. Se todos os campos estiverem so de um lado da casa, ´ uma antena diretiva como a Yagi pode ser escolhida, se nao uma antena dipolo de ˜ meia onda poderia ser usada tambem. ´
Se for necessario um alcance muito grande, poder ´ | a ser usado um amplificador ´
tambem. ´
4.4.4 Implementaçao no c ˜ | odigo ´
A comunicaçao com o m ˜ | odulo ´ | e feito por SPI, o comando ´ | e feito escrevendo em ´
registros dentro do modulo as configuraç ´ | oes ou dados a serem enviados. Os ˜ | drivers

Figura 4.20: Antena do modulo LoRa. Fonte: O Autor (2018) ´

para o modulo SX1278 se baseiam num c ´ | odigo por Wojciech Domski, dispon ´ | ível em
https://github.com/wdomski/SX1278. O codigo foi modificado para se adaptar ao ´
hardware em questao e foram feitas mudanças em algumas funç ˜ | oes com a finalidade ˜
de diminuir o circuito externo do modulo. ´

### 4.5 Bateria

A bateria e uma parte essencial para o funcionamento do projeto, se a bateria perde ´
muita tensao com a perda de carga, ela pode n ˜ | ao fornecer tens ˜ | ao suficiente para ˜
alimentar os componentes, o microcontrolador necessita 1, 8V para funcionar, o datasheet do chip LoRa SX1278 menciona o mesmo valor como valor mínimo, os
tres sensores n ˆ | ao s ˜ | ao sens ˜ | íveis a mudanças de tensao e funcionam desde que o ˜
ADC do microcontrolador esteja funcionando. Logo e necess ´ | aria uma bateria que ´
forneça a maior parte da sua carga antes de ficar com tensao inferior ˜ | à 1, 8V .
As principais baterias levadas em consideraçao foram: ˜

### 4.5.1 Bateria de íon-lítio

Muito usada para os mais diversos aparelhos eletronicos - desde celulares at ˆ | e baterias ´
de carros eletricos - por ter uma grande capacidade, por poderem suprir muita corrente ´
e por serem recarregaveis . Por ´ | em uma c ´ | elula de uma bateria como a 18650 pode ´
começar com uma tensao de at ˜ | e 4V, segundo o ´ | datasheet EEMB (2010), que passa do
limite tolerado pelo microcontrolador escolhido (STM32L051) de 3,6 V. Alem disso para ´ recarga este tipo de bateria demanda um circuito específico e complexo. A bateria de polímero de lítio possui uma desvantagem parecida com a de íon-lítio, com uma
tensao m ˜ | axima passando de 4,2 V ultrapassando a tens ´ | ao m ˜ | axima permitida pelo do ´
microcontrolador.

### 4.5.2 Pilha AA Alcalina

Uma bateria alcalina tem uma tensao nominal de 1,5 V, variando entre 1,5 V e 0,8 V. ˜
Se duas estiverem em serie, a tens ´ | ao fica entre 3 V e 1,6 V, onde uma grande parte ˜
fica dentro da faixa de funcionamento do microcontrolador, sem precisar de circuito adicional para regular a tensao. A pilha alcalina foi escolhida, devido a sua carga ˜

maior e uma auto-descarga menor comparada com uma bateria AA de zinco-carbono tradicional.

### 4.6 Microcontrolador

O microcontrolador STM32L051 foi escolhido pois a arquitetura ARM Cortex-M possui alta capacidade de processamento, associada a um baixo custo e baixo consumo de energia (linha M0+).
Como este projeto visa fazer um prototipo diretamente em uma PCB, o ´ microcontrolador foi soldado diretamente na placa desenvolvida na seçao 4.8. ˜
O microcontrolador possui inumeros perif ´ | ericos e funç ´ | oes essenciais para ˜
este projeto, sendo que os modulos utilizados neste projetos ser ´ | ao descritos na ˜
sequencia. ˆ
O esquematico do circuito, incluindo as conex ´ | oes do microcontrolador, est ˜ | á
disponível no anexo A.

### 4.6.1 Timers

O STM32L051 contem 9 ´ | timers, este periferico ´ | e usado em dois sensores, o sensor ´
de umidade do solo e do ar.
Sensor de umidade do solo
Este sensor usa o timer 2, em modo output compare para gerar uma onda quadrada de período 15ms.
Sensor de umidade relativa do ar
Usa dois timers, o 21 em modo output compare para gerar uma onda quadrada
de período de 256ms, e o 22 que e id ´ entico ao 21 mas est ˆ | a deslocado de ´ | 100ms para
acionar o ADC.

### 4.6.2 ADC

Usado pelos tres sensores, o ˆ | ADC do STM32L051 tem resoluçao de 12 bits, ˜
frequencia de amostragem de at ˆ | e 1.14 Msps e 16 canais, com um m ´ | ínimo de 1,65 V.
Outra característica deste periferico ´ | e que ele pode fazer sobre-amostragem ´
por hardware, diminuindo a carga do MCU.

### 4.6.3 Comparador

O periferico do comparador ´ | e usado para o sensor de umidade do solo, quando o sinal ´
do circuito RC for maior que um valor fixo dado por uma ponte resistiva, o comparador vai ter como saída 1, no caso contrario sera zero. ´

### 4.6.4 Interfaceamento

O interfaceamento do chip LoRa SX1278 e feito por meio de comunicaç ´ | ao SPI, o ˜
microcontrolador conta com um periferico SPI. ´

### 4.6.5 Osciladores

O circuito conta com dois osciladores, um de alta velocidade com 16 MHz, e outro
para o RTC de 32,768 kHz. Depois de todos os testes sera avaliado se estes s ´ | aõ
necessarios, pois se o oscilador interno for preciso o suficiente, uma boa parte da ´ PCB ficaria livre e seria possível faze-lo menor. ˆ

### 4.6.6 RTC

O MCU contem um ´ | real time clock integrado. Ele aceita como clock de entrada um
oscilador interno de 37kHz, ou um oscilador externo de baixa frequencia, normalmente ˆ
de 32, 768kHz. O RTC e muito importante pois ´ | e ele que tira o ´ | MCU do modo de baixo
consumo.
E programado um alarme para acordar o ´ | MCU a cada hora.

### 4.6.7 Modos de baixo consumo

Existem cinco modos de baixo consumo no STM32l051: LPRun, Sleep, LPSleep, Stop e Standby.
A tabela 4.4 resume os cinco modos de baixo consumo. O modo que consome
menos energia e o ´ | Standby, seguido pelo Stop. No modo Stop a SRAM e o estado
dos GPIOs sao mantidos, o ˜ | core e pausado, a execuç ´ | ao do programa se reinicia ap ˜ | os´
uma interrupçao vinda do ˜ | RTC.
No modo Standby, a SRAM e desenergizada e os ´ | GPIOs entram em alta
impedancia para economizar energia. Como a ˆ | SRAM nao guarda os conte ˜ | udos, todos ´
os valores guardados nela sao perdidos, ˜

Tabela 4.4: Tabela resumindo os modos de baixo consumo de energia, de melhor (1) ate pior (5). Fonte: Mielke (2017) ´

LPRun Sleep LPSleep Stop Standby
Performance | 1 | 2 | 3 | 4 | 5
Power Consumption | 4 | 5 | 3 | 2 | 1
Wake-up Sources | 1 | 2 | 3 | 4 | 5
Wake-up Time | 2 | 1 | 4 | 3 | 5
O modo escolhido para este projeto e o ´ | Stop, que tem um consumo muito
baixo de energia e guarda os conteudos da ´ | SRAM.

### 4.6.8 Botoes, LEDs e SWD ˜

Foi incluído um botao de ˜ | reset, para facilmente resetar o microcontrolador caso seja
necessario. | Dois LEDs foram inclu ´ | ídos na PCB, um e ligado diretamente na ´
alimentaçao, para mostrar que a alimentaç ˜ | ao est ˜ | a correta (este ser ´ | a futuramente ´
retirado para diminuir o consumo de energia) e outro esta ligado em um ´ | GPIO para
uso geral, como por exemplo para mostrar quando o dispositivo esta transmitindo. ´ Foi feita uma conexao SWD para que o microcontrolador possa ser ˜ programado com um dispositivo ST Link.

### 4.7 Firmware

A figura 4.21 exemplifica a interaçao entre os diferentes m ˜ | odulos do ´ | firmware. A
informaçao entra pelos tr ˜ | es sensores, ˆ | e tratada pelo agendador de tarefas ´
(scheduler) e entao encaminhada para o m ˜ | odulo ´ | LoRa.

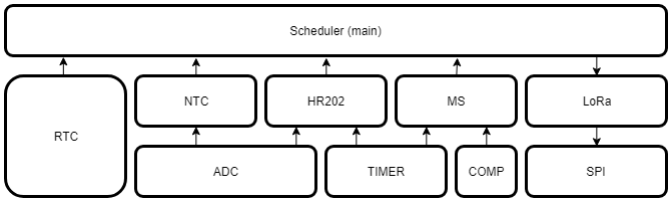
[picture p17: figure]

Figura 4.21: Diagrama da interaçao entre os m ˜ | odulos. Fonte: O Autor (2018) ´
O codigo para cada m ´ | odulo ou sensor foi explicado na pr ´ | opria seç ´ | ao dedicada ˜
a cada sensor, todos os codigos foram escritos de forma modular, para manter boas ´
praticas de programaçao e para evitar ˜ | bugs.
A funçaõ main do firmware consiste em inicializar todos os perifericos, coletar ´
as informaçoes dos tr ˜ | es sensores, enviar as informaç ˆ | oes via ˜ | LoRa, e entrar em modo
de baixo consumo ate que o ´ | RTC acorde o MCU para recomeçar este processo.

### 4.8 Desenvolvimento da PCB

O desenvolvimento da PCB foi feito no software KiCAD. O esquematico geral do ´ circuito esta presente no anexo A. ´
Para o roteamento da PCB foi tomado muito cuidado para que esta possa ser
feita em casa, com metodos caseiros, para poder fazer um prot ´ | otipo rapidamente. A ´
placa tem duas camadas, mesmo sendo possível fazer em uma, pois o sensor de umidade do solo tem uma sensibilidade bidirecional se ele se estende nas duas camadas, alem de aumentar a sensibilidade. ´
O roteamento foi feito tentando preservar ao maximo o plano de massa para ´ melhorar o desempenho da placa. O layout da placa, pode ser visto na figura 4.22

### 4.9 Gateway LoRa

O gateway LoRa consiste em um modulo LoRa SX1278, ligado ao microcontrolador ´
STM32F103 via SPI, e este ligado a uma ` | SBC Raspberry Pi via UART para
processamento, armazenamento e divulgaçao dos dados na rede local. ˜
O diagrama da figura 4.23 representa estas ligaçoes. ˜
Uma vez o dado adquirido e processado (como explicado nas seçoes ˜
dedicadas a cada sensor), os dados sao armazenados num banco de dados ˜ | SQLite.
As colunas deste banco de dados sao: o n ˜ | umero da mensagem geral (entre todos os ´

(a) Camada superior da PCB. | (b) Camada inferior da PCB.

Figura 4.22: Layout da PCB. Fonte: O Autor (2018)

Figura 4.23: Diagrama de conexoes do ˜ gateway. Fonte: O Autor (2018)

dispositivos), a data e hora de recebimento, a temperatura, a umidade do ar e do solo, o numero da mensagem deste dispositivo, e o identificador do dispositivo. ´

CAPÍTULO 5

RESULTADOS

### 5.1 Placa de circuito impresso

A PCB foi desenvolvida com o metodo fotossens ´ | ível, pois este e mais preciso que o por ´
transferencia t ˆ | ermica, j ´ | a que a placa cont ´ | em um chip com espaçamento de ´ | 0, 5mm,
com trilhas e espaçamento de 0, 25mm. Este metodo consiste em aplicar um filme ´ sobre a placa de cobre, cobrir a placa de cobre com o fotolito onde esta impresso o
layout do circuito, logo e usada uma l ´ | ampada ultravioleta para revelar as partes que ˆ
devem ficar com cobre. Apos a revelaç ´ | ao dos dois lados, ˜ | e inserida a placa em uma ´
soluçao para retirar a parte que n ˜ | ao foi revelada, e ent ˜ | ao imersa em percloreto de ferro ˜
para retirar o cobre, e finalmente em uma outra soluçao para retirar a tinta revelada. ˜

### 5.1.1 Versoes de hardware da PCB ˜

Foram feitas algumas versoes de hardware diferentes, as vers ˜ | oes foram evoluindo de ˜
acordo com dificuldades para fazer a placa ou por causa de erros na placa. A figura 5.1 mostra estas placas.
A ultima versaõ e a vers ´ | ao v1.2 (figura 5.2). ˜

### 5.2 Sensor de temperatura

A placa faz a aquisiçao dos sinais e os envia em dados brutos, ou seja, a leitura direta ˜ do ADC (depois de feita a sobre-amostragem).
A aquisiçaõ e feita rapidamente, ´ | e energizado o sensor, se faz a aquisiç ´ | aõ
pelo ADC (com sobre-amostragem por hardware), e entao tudo ˜ | e desligado, como se ´
pode ver na figura 5.3.
No gateway for escolhida a equaçao 4.2, polinomial de terceira ordem para ˜
relacionar a tensao de sa ˜ | ída com a temperatura.
A figura 5.10 mostra o resultado da medida de temperatura no banco de dados do gateway.

### 5.2.1 Calibraçaõ

A calibraçao do sensor de temperatura foi feita adquirindo medidas de resist ˜ | | | | encia do ˆ
sensor em varias temperaturas conhecidas, as medidas foram feitas em um recipiente ´
com agua e gelo, na temperatura ambiente e em um recipiente com ´ | agua em ebuliç ´ | ao, ˜
com a ajuda de um termometro calibrado. Os resultados est ˆ | ao presentes na tabela ˜
5.1. Utilizando a equaçao 5.1 e os dados coletados, ˜ | e calculada a constante ´ | B para
cada par de dados, e finalmente a constante escolhida para calibraçaõ e a m ´ | edia entre ´
os tres valores de ˆ | | B calculados.

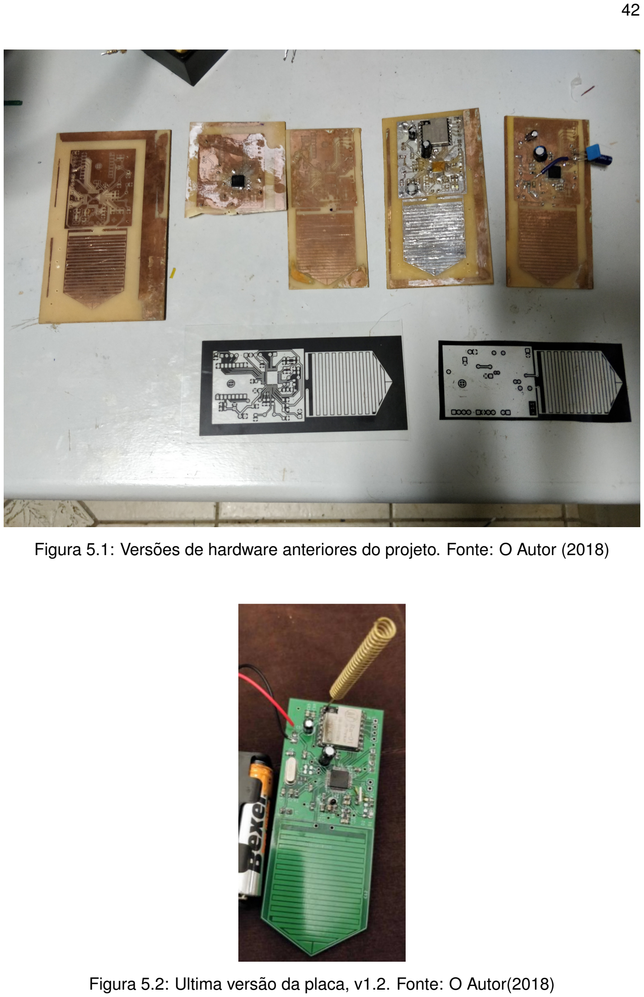
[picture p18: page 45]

Figura 5.1: Versoes de hardware anteriores do projeto. Fonte: O Autor (2018) ˜

Figura 5.2: Ultima versao da placa, v1.2. Fonte: O Autor(2018) ˜

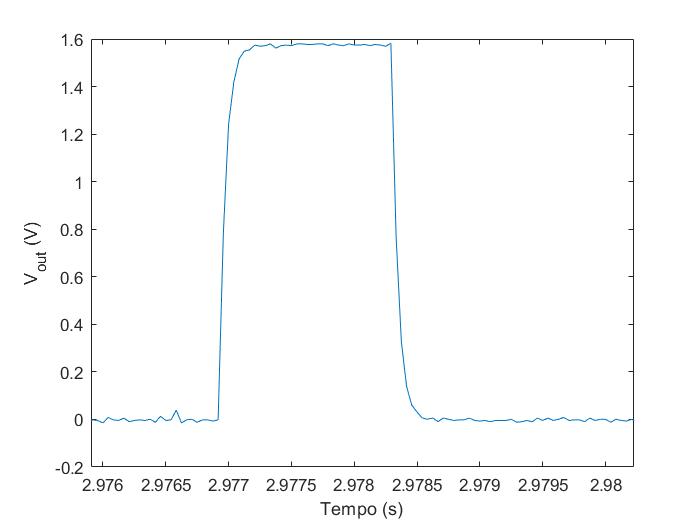
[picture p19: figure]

Figura 5.3: Tensao de sa ˜ | ída na aquisiçao da temperatura. Fonte: O Autor (2018) ˜
Tabela 5.1: Informaçoes sobre a calibraç ˜ | ao do sensor NTC. Fonte: O Autor(2018) ˜
T ( C ) | T (K) | R (Ohms) | B (K)
0 | 273.15 | 31570 | 3931.76320918964
19 | 292.15 | 12380 | 4073.91862681217
82.1 | 355.25 | 1040 | 4033.91475238639
| | Media ´ | 4013.19886279607

B =

ln(RT1/RT2
1/T1 − 1/T2

(5.1)

Usando esta calibraçao e a equaç ˜ | ao 4.2 para fazer a transiç ˜ | ao entre a tens ˜ | aõ
de saída e a temperatura, obtemos os erros apresentados na tabela 5.2, o erro e alto ´
para altas temperaturas, mas como estas nao ser ˜ | ao usadas, isto n ˜ | aõ e um problema. ´

Tabela 5.2: Erro do sensor de temperatura nas temperaturas de calibraçao. Fonte: O ˜ Autor (2018)

T ( C ) | Erro ( C )
0 | 1,65
19 | 0,52
82.1 | -5,47

### 5.3 Sensor de umidade do solo

Na figura 5.4 se encontra a tensao de sa ˜ | ída no pino de entrada, onde esta o circuito ´
RC, com um capacitor de 470pF, e o resistor de 240kΩ. O sensor faz oito medidas no total, quando o sinal muda de estado.
Figura 5.4: Tensao de sa ˜ | ída do sensor de umidade do solo, teste com o capacitor.
Fonte: O Autor (2018)

A figura 5.5 mostra a o resultado da mediçao de umidade do solo. O sensor ˜ esta inserido dentro do solo, na primeira e na segunda linha, se pode ver que a ´
umidade do solo (quinta coluna) esta baixa, ent ´ | ao um pouco de ˜ | agua ´ | e adicionada a ´
terra perto do sensor e a umidade aumenta significativamente (terceira linha), e depois de um tempo a agua se espalha pela terra, diminuindo um pouco a umidade ´ do solo perto do sensor (quarta linha).
Figura 5.5: Demonstraçao do aumento da grandeza medida quando ˜ | e colocado mais ´
agua na terra onde se encontra o sensor. Fonte: O Autor (2018) ´

### 5.3.1 Calibraçaõ

Para confirmar que o circuito proposto mede corretamente a capacitancia, foram ˆ usados capacitores com valores conhecidos para testar a performance do sistema. A
tabela 5.3 contem dados dos v ´ | arios capacitores testados, o valor nominal deles e o ´
valor encontrado pelo algoritmo.
Se o valor obtido for subtraído dos valores a vazio, quando nada está
conectado (ou seja, a capacitancia parasita), se obt ˆ | em valores muito pr ´ | oximos dos ´

Tabela 5.3: Resultado do teste do sensor de umidade do solo com capacitores conhecidos. O valor ”count”se refere ao valor obtido pelo sensor subtraído do sensor em aberto. Fonte: O Autor (2018)

Capacitor | Count | C (F)
Aberto | 0 | 0
2,2p | 2 | 1,50E-12
5p | 5 | 3,76E-12
15p | 20 | 1,50E-11
220p | 293 | 2,20E-10
470p | 629 | 4,73E-10
1 n | 1342 | 1,01E-09
10 n | 12945 | 9,73E-09
valores nominais de capacitancia, e dentro da toler ˆ | ancia dos capacitores, como visto ˆ
na tabela 5.3.
Para a calibraçao do sensor em si, ˜ | e usado o m ´ | etodo gravim ´ | etrico, que ´
consiste em tres etapas: ˆ
1. Pesar as amostras do solo.
2. Colocar amostras em uma estufa por 24-48h em uma temperatura entre 95 C e 105 C.
3. Pesar as amostras novamente.

Como as amostras ficaram na estufa por muito tempo, a agua evapora e a ´
diferença entre as massas medidas era em agua, e ent ´ | aõ e poss ´ | ível calcular a
umidade do solo com a equaçao 5.2, onde ˜ | Mm e a massa da amostra molhada, ´ | Ms é
a massa da amostra seca, e Mr e a massa do recipiente. ´

MS =

| Mm − Ms
| Ms − Mr

(5.2)

Este metodo foi seguido, com tr ´ | es amostras (T1, T2 e T3), para calibrar o ˆ
sensor, o resultado esta na tabela 5.4. ´
Tabela 5.4: Medidas para a calibraçao do sensor de umidade do solo via m ˜ | etodo ´
gravimetrico. Fonte: O Autor(2018) ´
Amostra | T1 | T2 | T3 | Agua ´
Mr (g) | 4 | 5 | 6 | -
Mm (g) | 24 | 29 | 29 | -
Ms (g) | 18 | 20 | 20 | -
Cont | 935 | 1248 | 1578 | 2313
C (pF) | 702.56 | 937.75 | 1185.71 | 1737.99
MS (%) | 42.86 | 60 | 64.29 | 101.7*
A partir destas medidas, ` | e poss ´ | ível utilizar fazer uma regressao linear para ˜
obter a equaçao que relaciona a capacit ˜ | | ancia com a umidade do solo. A figure 5.6 ˆ

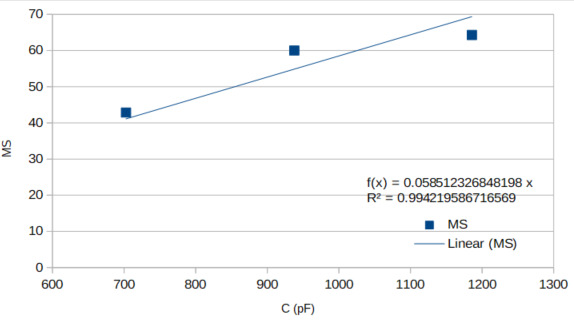
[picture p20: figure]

Figura 5.6: Regressao linear das medidas obtidas para obtenç ˜ | ao da equaç ˜ | ao que ˜
relaciona capacitancia do sensor com umidade do solo. Fonte: O Autor (2018) ˆ
mostra este calculo feito no Libreoffice Calc, de onde se pode tirar a equaç ´ | ao (5.3) ˜
que relaciona a capacitancia com a umidade do solo, na equaç ˆ | ao, ˜ C e medido em ´ | pF,
esta equaçao apresenta um coeficiente de determinaç ˜ | ao ( ˜ | R²
) de 0, 994.
MS = 0, 0585 · C | (5.3)
Na tabela 5.4 tambem foi feito um teste com ´ | agua, e foi calculada a umidade ´
do solo a partir da medida da capacitancia. Como ˆ | e esperado, o valor ´ | e muito pr ´ | oximo ´
de 100%.
Lembrando que estes valores so servem para o tipo de solo testado, para ´
outro tipo de solo seria necessario fazer uma recalibraç ´ | ao. ˜

### 5.4 Sensor de umidade relativa do ar

A placa faz a aquisiçao dos sinais e os envia em dados brutos, ou seja, diretamente a ˜ leitura do ADC (depois de feita a sobre-amostragem).
A figura 5.7 mostra a tensao de sa ˜ | ída quando o sensor e acionado. Como foi ´
mencionado na parte 4.3, o ADC tem que ser sincronizado com o timer que comanda
a onda quadrada, na figura 5.7 e poss ´ | ível ver quando o ADC termina sua conversao. ˜
Desta maneira as medidas do ADC nao s ˜ | ao afetadas pelas componentes capacitivas ˜
do sensor.
Existe um pequeno overshoot devido a capacitancia, por ˆ | em´ | e um valor ´
aceitavel, quando a resist ´ | encia ou capacit ˆ | ancia do sensor aumentarem, este ˆ
overshoot e o tempo que demora para ficar estavel podem mudar, como pode ser ´ visto em uma outra aquisiçao feita (figura 5.8). ˜
A figura 5.10 mostra o resultado da medida de umidade relativa do ar, onde a
medida ja foi processada e armazenada num banco de dados no ´ | | gateway.

### 5.4.1 Calibraçaõ

Para que o sensor seja calibrado, e necess ´ | aria a obtenç ´ | ao de um valor conhecido de ˜
umidade do ar. Para isto, dentro de um recipiente fechado foi colocada uma soluçaõ

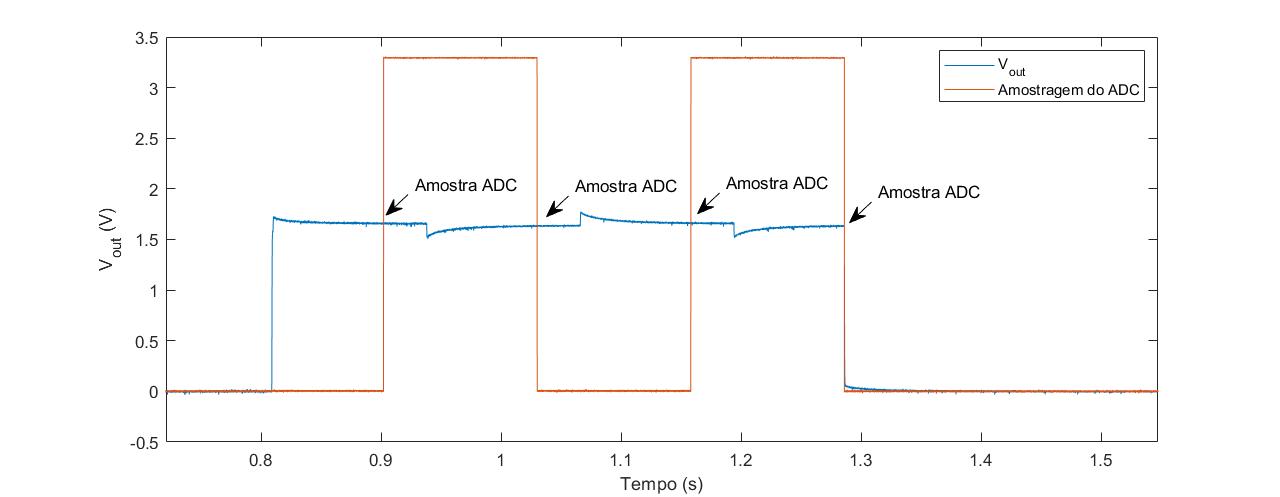
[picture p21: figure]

Figura 5.7: Tensao de sa ˜ | ída na aquisiçao da umidade relativa do ar. Fonte: O Autor ˜
(2018)

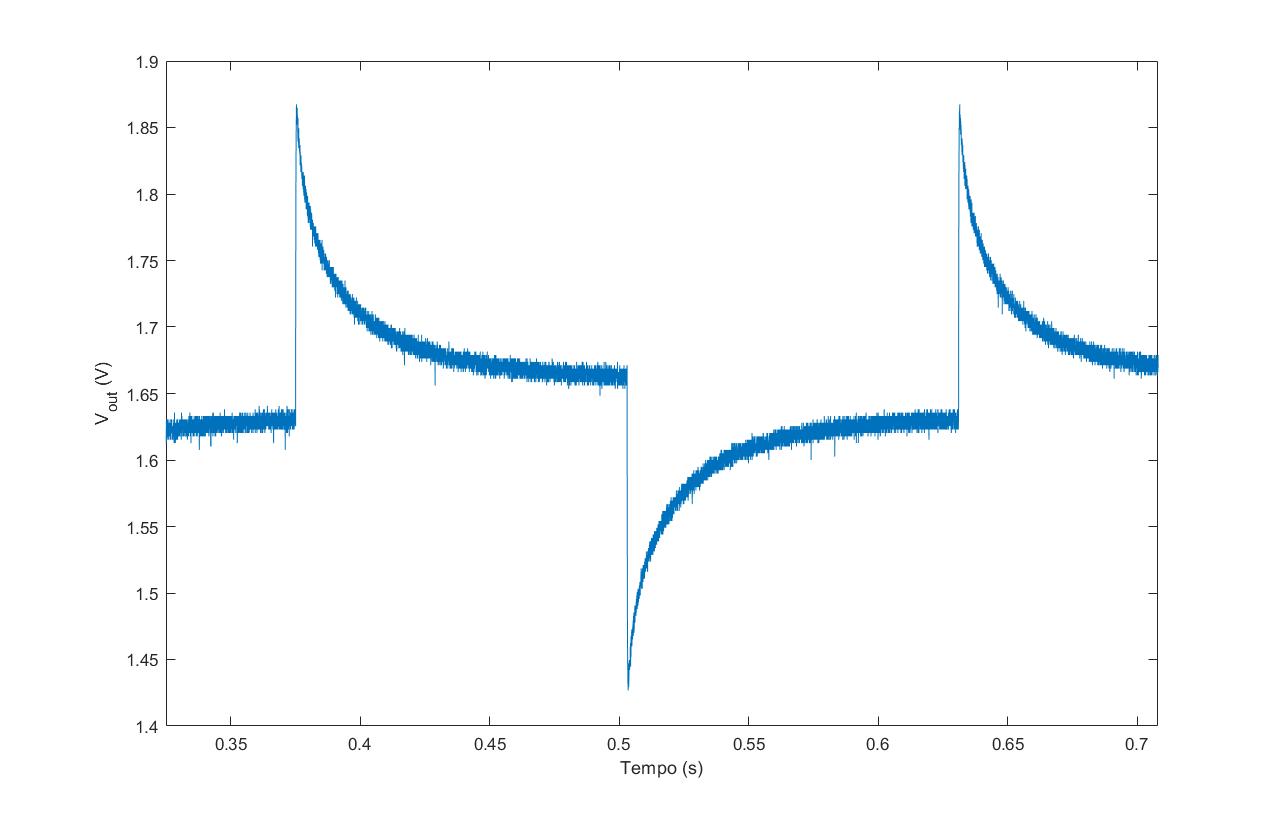
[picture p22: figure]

Figura 5.8: Tensao de sa ˜ | ída quando o efeito da capacitancia ˆ | e mais forte. Fonte: O ´
Autor (2018).

saturada de sal (sal com algumas gotas de agua), que fazem com que a umidade ´ relativa do ar com o tempo seja 75%. Alem disso foi usado um outro sensor de umidade ´
do ar (este ja calibrado), para obter mais pontos de comparaç ´ | | ao. ˜
Em um primeiro momento, o sensor de umidade do ar do dispositivo naõ
alegou uma umidade do ar de 75% dentro do recipiente, porem o sensor de refer ´ | encia ˆ
mede exatamente o valor esperado, logo este esta calibrado. ´
Para compensar o sensor do dispositivo, foram retirados do recipiente os dois sensores e anotados novamente as medidas feitas, estas medidas e as medidas do recipiente estao presentes na tabela 5.5, e com estes dados da tabela foi feita uma ˜ equaçao para relacionar o valor alegado pelo sensor do dispositivo com o valor real, ˜
que esta presente na equaç ´ | ao 5.4. ˜
RHreal = 2RHdisp − 18, 12 | (5.4)
Apos a calibraç ´ | ao, foi feita uma nova tentativa para medir a umidade relativa do ˜
ar quando o dispositivo e colocado dentro do recipiente com a soluç ´ | ao de sal saturada. ˜

Tabela 5.5: Valores para calibraçao do sensor de umidade relativa do ar. Fonte: O ˜ Autor(2018)

| Ambiente | Recipiente
Valor medido | 42.2 | 46.715
Valor real | 66 | 75
O resultado esta na figura 5.9, que mostra a evoluç ´ | ao da vari ˜ | avel em funç ´ | ao do tempo ˜
ate ela se estabilizar perto de ´ | 75%,o que mostra que o sensor foi calibrado.

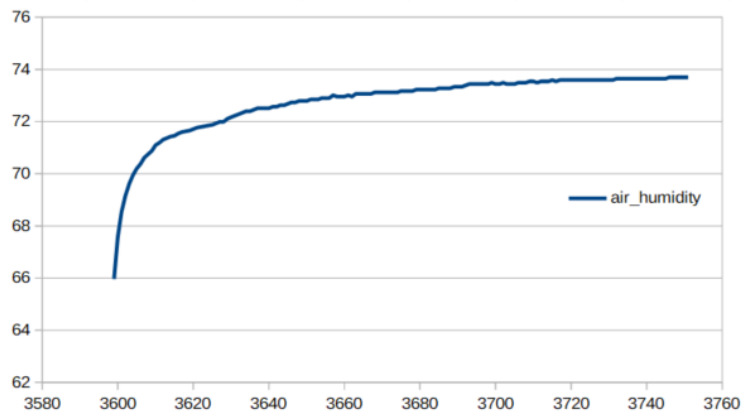
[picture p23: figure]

Figura 5.9: Evoluçao da umidade relativa do ar dentro do recipiente com uma soluç ˜ | aõ
de sal saturada, mostra que o sensor esta calibrado. Fonte: O Autor(2018) ´

### 5.5 Comunicaçao LoRa ˜

Foi testada o alcance do sistema, o teste foi feito dentro da cidade com muitos
predios e desn ´ | íveis, logo nao representa muito bem a situaç ˜ | ao do campo, por ˜ | em´
mesmo nessas condiçoes adversas o receptor conseguiu receber mensagens em at ˜ | é
1, 4km de distancia. ˆ
O dispositivo para testes manda uma mensagem por minuto, para ajudar na
validaçao e calibraç ˜ | ao dos resultados, o dispositivo final manda uma mensagem por ˜
hora.

### 5.6 Consumo de energia

A tabela 5.6 mostra os estados mais importantes, seus consumos respectivos e o tempo que o dispositivo fica em cada estado.

Considerando duas bateria de 2000mAh cada uma, uma mensagem por hora, e a tabela 5.6, o dispositivo funcionaria sem trocar a bateria por aproximadamente 1
ano e 4 meses (equaçao 5.5). Neste c ˜ | alculo ´ | e desconsiderada a energia necess ´ | aria ´
para adquirir as amostras, pois e um valor irris ´ | | orio comparado com os outros. ´

Tabela 5.6: Corrente utilizada pelo dispositivo em diferentes modos. Fonte: O Autor (2018)

Estado | Corrente (mA) Tempo
Transmitindo | 70 | 900 ms
Stop | 0,320 | 1 h

d =

4000mAh
0, 320mA · 1 + 70mA · 0, 9/3600
= 1, 35anos | (5.5)

### 5.7 Gateway

Os dados sao adquiridos e armazenados num banco de dados ( ˜ | | SQLite) dentro de um
computador de placa unica ( ´ | Raspberry Pi). E poss ´ | ível de obter os dados armazenados
no banco de dados com comandos SQL. A figura 5.10 mostra um exemplo dos dados coletados, onde todos os sensores estao presentes. ˜

Figura 5.10: Valores coletados pelo sensor e enviados para o gateway via LoRa e armazenados. Fonte: O Autor (2018).

Uma interface web para o banco de dados SQLite foi instalada no gateway, esta interface se chama phpLiteAdmin (https://www.phpliteadmin.org/), e ela possibilita
a facil manipulaçao e visualizaç ˜ | ao dos dados do servidor em qualquer computador da ˜
rede local, uma vez que tambem foi instalado um servidor HTTP (Apache) no ´ | gateway.
Um exemplo desta interface pode ser visto na figura 5.11

### 5.8 Preço estimado

O preço foi calculado desconsiderando os custos de resistores e capacitores, na tabela 5.7 se encontram os componentes principais considerados e os seus preços respectivos para baixas quantidades (dez unidades ou menos), o calculo foi feito com ´ 1USD = 3, 74BRL.

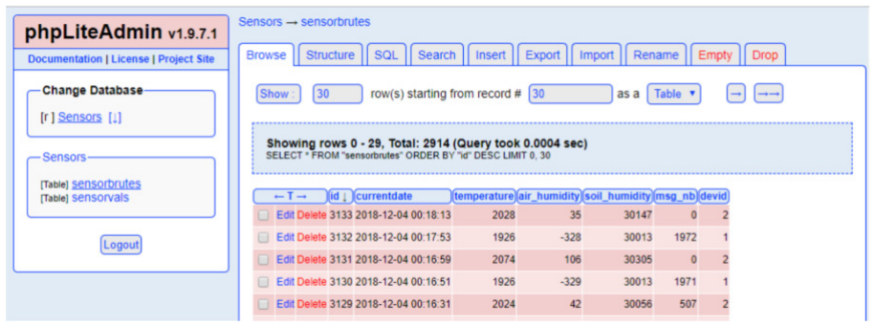
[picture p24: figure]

Figura 5.11: Interface phpLiteAdmin para o banco de dados SQLite. Fonte: O Autor (2018)

Tabela 5.7: Tabela contendo os preços aproximados para a placa.

Componente | Preço (USD)
NTC | 0,10
HR202 | 0,52
MCU | 2,71
LoRa | 2,52
PCB | 0,80
Total (USD) | 6,65
Total (BRL) | 24,90

CAPÍTULO 6

CONCLUSAÕ

Este projeto oferece uma soluçao de baixo custo e grande alcance e autonomia para ˜
a mediçao de temperatura, umidade do solo e do ar, para ser aplicado nas plantaç ˜ | oes. ˜
O Brasil possui uma grande parte de seu territorio dedicada a plantaç ´ | oes, ˜ | e essencial ´
a aplicaçao da tecnologia nesses lugares para o aumento de produtividade. O projeto ˜ é open source e open hardware, e livre para que qualquer pessoa possa utiliza-lo, os ´
arquivos do projeto estao dispon ˜ | íveis em https://github.com/patricktlo/IotSoilSensor.
O projeto atinge seu objetivo geral, desenvolvendo um prototipo para mostrar ´ que e poss ´ ível realizar um produto com o intuito de medir a temperatura, a umidade do solo e do ar, com transmissao por rede Lora, baixo custo do dispositivo e grande ˜ autonomia. O projeto foi desenvolvido com o intuito de otimizar esses itens. Foram escolhidos como microcontrolador um STM32L051, como sensor de temperatura um NTC, como sensor de umidade relativa do ar um HR202, como chip para a rede LoRa um SX1278, como bateria duas pilhas AA alcalinas e foi desenvolvido o sensor de umidade do solo na PCB, que nao interage com o solo pois faz suas medidas com a ˜ capacitancia do sensor. ˆ
O custo total de cada dispositivo e de aproximadamente 25 reais, e sua ´ autonomia em bateria de aproximadamente um ano e quatro meses.
Alem do prot ´ | otipo do dispositivo foi feito um ´ | gateway que recebe as
informaçoes brutas do sensor, processa, armazena e divulga essas informaç ˜ | oes por ˜
meio de uma base de dados SQLite. Esta estrutura e feita com um ´ | Raspberry Pi,
alem de um microcontrolador ´ | STM32F103 para interagir com o chip para a rede
LoRa, SX1278. O banco de dados tem a capacidade de distinguir cada aparelho e a data em que foi enviada a mensagem.
Sugestoes para melhoria do projeto incluem a mudança da antena do ˜
gateway para uma antena mais eficiente, a adiçao de sensores ˜ | uteis para a ´
agricultura como sensor de pH e de nutrientes, escrever um software para que se possa visualizar em um mapa os valores dos diversos sensores, facilitando a
visualizaçao e a an ˜ | alise de dados para as pessoas. Para melhorar a precis ´ | ao do ˜
sensor de umidade do ar e poss ´ | ível fazer uma interpolaçao por splines, tanto da ˜
temperatura quando da resistencia, e para melhorar a precis ˆ | ao do sensor de ˜
temperatura, utilizar a equaçao de Steinhart-Hart para o NTC ao inv ˜ | es da equaç ´ | aõ
exponencial, e para melhorar ainda mais a vida util do dispositivo, diminuir o consumo ´ do MCU em modo de economia de energia, usando por exemplo o modo standby.

BIBLIOGRAFIA

DEAN, R. N. et al. A capacitive fringing field sensor design for moisture measurement based on printed circuit board technology. IEEE Transactions on Instrumentation and Measurement, v. 61, n. 4, p. 1105–1112, April 2012. ISSN 0018-9456.

EEMB. Lithium-ion Battery DATA SHEET. [S.l.], 1 2010. Rev. 1.

ELECROW. HR202 Humidity Sensor. [S.l.].

FIESP, D. Balança Comercial Brasileira do Agronegocio - Agosto 2018 ´ | .
2018. <http://www.fiesp.com.br/indices-pesquisas-e-publicacoes/balanca-comercial/attachment/file-20180918140623-bca2018/. Acesso em 24/09/2018.

GOSWAMI, M. P.; MONTAZER, B.; SARMA, U. Design and characterization of a fringing field capacitive soil moisture sensor. IEEE Transactions on Instrumentation and Measurement, p. 1–10, 2018. ISSN 0018-9456.

MIELKE, M. Low-Power Modes on the STM32L0 Series. 9
2017. Https://www.digikey.com/eewiki/display/microcontroller/Low-Power+Modes+on+the+STM32L0+Series.

MIZUGUCHI, J. et al. Fringing field capacitive sensor for measuring soil water content: Design, manufacture, and testing. IEEE Transactions on Instrumentation and Measurement, v. 64, n. 1, p. 212–220, Jan 2015. ISSN 0018-9456.

NENOV, T.; IVANOV, S. Linearization of characteristics of relative humidity sensor and compensation of temperature impact. Sensors and Materials, v. 19, n. 3, p. 95–106, 2007.

SEMTECH. SX1276/77/78/79 - 137 MHz to 1020 MHz Low Power Long Range Transceiver. [S.l.], 3 2015. Rev. 4.

APENDICE A ˆ

ESQUEMATICO COMPLETO DO CIRCUITO ´

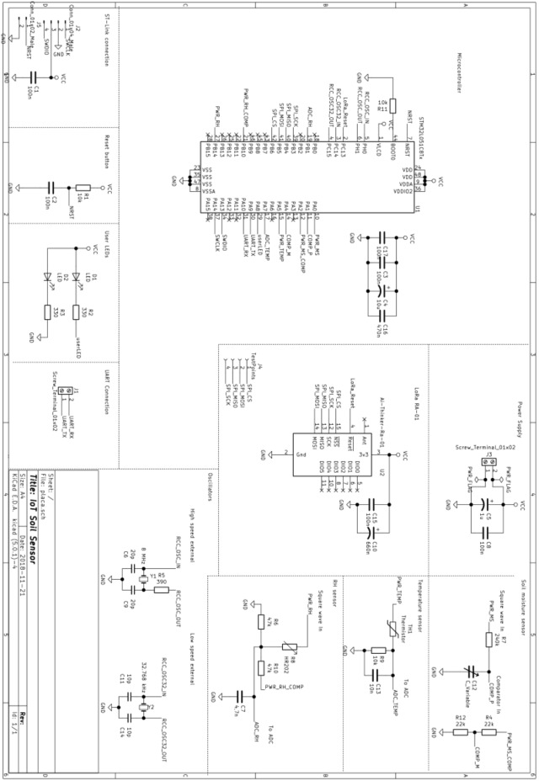
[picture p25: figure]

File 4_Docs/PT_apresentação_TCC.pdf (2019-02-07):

# DESENVOLVIMENTO DE UMA SOLUÇÃO IOT

PARA MEDIDA REMOTA DE TEMPERATURA,

# UMIDADE DO AR E DO SOLO COM BAIXO CUSTO E BAIXO CONSUMO DE ENERGIA

## Nome: Patrick Thierry Lorusso El Omairi GRR: 20133823 Professor orientador: Prof. Dr. Márlio José Do Couto Bonfim

# Agenda

# - 1. Introdução - Problema - 2. Objetivos gerais - 3. Objetivos específicos

# - 4. Metodologia - 5. Desenvolvimento - 6. Resultados

# - 7. Melhorias - 8. Conclusão

# - 9. Bibliografia

# 1. Introdução - Problema

⚫ | Área de lavouras no Brasil: 639945 km2
⚫ | Dos quais 351000 km2 de soja

Equivalente a área da França.

## Equivalente a área da Alemanha


⚫ | 47% dos agricultores brasileiros não utilizam nenhum tipo de agricultura de precisão no Brasil (PAPP, 2014)
⚫ | Agricultura 4.0: Facilidade na obtenção de dados. IoT e big data aplicados para o campo. (FONTES, 2017)

## (LIMA, 2017) (EMBRAPA, 2018)

# Desenvolver um dispositivo eletrônico capaz de


# 2. Objetivos gerais

# medir temperatura, umidade relativa do ar e do

solo, e enviar os dados por uma rede IoT Lora.

# Todos os sensores devem ser integrados junto do MCU em uma só placa de baixo custo e

baixo consumo de energia.

# 3. Objetivos específicos

Desenvolvimento do hardware.; Simulação no LTSpice ou em Python; Desenvolvimento da placa de circuito impresso.; Teste do hardware; Desenvolvimento do software embarcado para STM32; Implementação da comunicação via rede LoRa

4. Metodologia; Desenvolvimento Hardware; • Escolha dos componentes.; • Circuito do microcontrolador.; Simulação do Hardware; • LTSpice • Python (modelação por equações) • FEMM; Teste do hardware; • Testes em bancada; Desenvolvimento da PCB; • Software: KiCAD • Fabricação: Método fotossensível; Software embarcado (STM32); • Desenvolvimento em C; Comunicação via LoRa; • Definição da payload. • Definição de parâmetros de rede.; • Desenvolvimento de um gateway.

- Circuito de condicionamento dos sensores.
- Circuito para o módulo de transmissão (LoRa)
- Usando Atollic TrueSTUDIO e STM32CUBEMX)

# 5. Desenvolvimento HW

## - Escolha dos componentes

Função | Componente
Sensor temperatura | NTC
Sensor umidade do ar | HR202
Sensor umidade do solo | Integrado na PCB – Capacitivo.
Bateria | 2 Pilhas AA alcalinas.
Microcontrolador | STM32L051
Modulo LoRa | Ra-01

# 5. Desenvolvimento - Sensor de temperatura

## NTC

⚫ | Resistência que varia com a temperatura.
⚫ | Não depende de Vcc

## Resistor de linearização escolhido pelo

método de inflexão.

## Rs = 7k

# 5. Desenvolvimento - Sensor de temperatura


# 5. Desenvolvimento – Sensor de umidade do ar

HR202

## Sensor de umidade do ar, varia sua resistência de acordo com a umidade do ar. Necessária a

aplicação de uma tensão alternada.

## Datasheet fornece uma tabela com valores de

resistência relacionados com RH.

## Não depende de Vcc


## Resistor de linearização escolhido pelo método

de inflexão.

## Rs = 39k

# 5. Desenvolvimento – Sensor de umidade do ar

# 5. Desenvolvimento – Sensor de umidade do ar

⚫ | Sincronização da onda quadrada com o ADC por meio de timers.
⚫ | Efeito capacitivo do sensor.

# 5. Desenvolvimento– Sensor de umidade do solo


Sensores capacitivos são eficientes para medir a quantidade de água em diferentes materiais, uma vez que a água tem uma permissividade elétrica muito superior à outros objetos. (DEAN et al, 2012)

Além de medir a umidade do solo, sensores capacitivos podem medir:

Umidade em grãos,
papel
Detecção de chuva
Sensor de proximidade
Botões capacitivos

Outras maneiras de medir a umidade do solo incluem:

Propagação de ondas
sísmicas
Sonda de neutros ou
raios gama
Reflectometria no
domínio do tempo (TDR)

# 5. Desenvolvimento– Sensor de umidade do solo

## Desenvolvimento de um sensor capacitivo

integrado na PCB.

## Para obter a geometria do sensor, foi simulada a

geometria no software FEMM.

## Devido a uma boa capacitância e uma boa penetracão no solo, foram escolhidos

## W = 1,5 mm

## D = 0,3 mm

A capacitância varia entre 57 e 740 pF.

## (MIZUGUCHI, 2015)

# 5. Desenvolvimento– Sensor de umidade do solo

## - Desenvolvimento do sensor no KiCAD


## Mesmo valor da constante

RC, | tanto | na | subida
quando na descida.

# 5. Desenvolvimento – Sensor de umidade do solo

5. Desenvolvimento – Bateria; Foram escolhidas duas pilhas alcalinas AA como bateria para o projeto.; Faixa de tensão adequada para maior vida útil do sistema (3V – 2V).; Não necessita de um circuito de condicionamento.

5.

# Desenvolvimento – MCU

STM32L051

Baixo
consumo

Baixo
custo
(US$
1,28)

ARM
Cortex
M0+

# 5. Desenvolvimento – MCU – Low power

## O microcontrolador STM32L051 possui 5 modos low power:

## O modo escolhido foi Stop, o MCU consome 320 uA quando está neste modo. Um RTC é

utilizado para tirar o MCU do modo stop a cada hora.

## Com duas pilhas AA Alcalinas de 4000 mAh, o dispositivo fica funcionando por 1 ano e 4

meses.

# 5. Desenvolvimento – LoRa

## LoRa

## Rede de baixo consumo Longo alcance Baixa taxa de transmissão Feito para dispositivos IoT

## Ra-01 (Baseado no chip

SX1278)

## Interface por SPI Baixo custo (US$ 3,65) 433 MHz

# 5. Desenvolvimento – Firmware


# 5. Desenvolvimento – MCU

## Desenvolvimento do projeto com a IDE Atollic

TrueSTUDIO e STM32CubeMX.


# 5. Desenvolvimento – PCB

## Desenvolvido com o software Kicad

# 5. Desenvolvimento – Gateway

## Processamento dos dados brutos dos sensores em Python no

Raspberry Pi.

## Raspberry Pi disponibiliza os dados na LAN via um banco de

dados SQLite.

## Desenvolvimento de um servidor HTTP (Apache) e utilização do PHPLiteAdmin como interface web para o banco

de dados.

# 5. Desenvolvimento – Banco de dados

# Duas tabelas foram criadas: Uma com os valores brutos enviados pelos sensores e uma com os valores

processados.

# Isto facilita a detecção de

anomalias nas medidas.

# As seguintes colunas são utilizadas

# 6. Resultados - Sensor de temperatura - Calibração

Aquisição da resistência do sensor em certas situações: Erro em cada ponto de medida, usando o polinômio de ordem 3.

(AMETHERM)

## Para tratar o sinal na gateway, é utilizada a curva polinomial, a equação fica:


# 6. Resultados - Sensor de temperatura


# 6. Resultados – Sensor de umidade do ar Calibração

## - Uma solução saturada de cloreto de sódio em água em um recipiente selado

gera uma umidade relativa do ar de 75%.

## - Calibração feita com outro sensor de

umidade do ar, para obter outros pontos.

# 6. Resultados – Sensor de umidade do ar


# Como este sensor depende da temperatura e da resistência. é feita uma interpolação linear no gateway para a resistência e usada a temperatura mais próxima

das da tabela.

# 6. Resultados – Umidade do solo Calibração

## Teste do sensor com capacitores conhecidos


# 6. Resultados – Umidade do solo Calibração


## Método gravimétrico

1) Pesar as amostras do solo.

## 2) Colocar amostras em uma estufa por 24-48h

em uma temperatura entre 95 C e 105 C.
3) Pesar as amostras novamente.

## Com estas informações basta usar a equação ao lado:

# 6. Resultados – Umidade do solo


## Alcance: 1,4 km

6.

# Resultados – LoRa

## Spreading factor: 12

## Consumo de energia: 70 mA @ 3V por

0,9 s

## Payload: 10 bytes

# 6. Resultados – Gateway



# 6. Resultados – Fabricação PCB

## - Feito pelo método fotossensível

## - Trilhas e espaçamentos de até 0,25 mm



## 6. Resultados – Preço

# 7. Melhorias

Equação de Steinhart-Hart para calibração do NTC.

Melhorar calibração do sensor de umidade do ar.

## Utilizar uma interpolação por splines (ou bilinear) para melhorar os dados do sensor de

umidade do ar, tanto da temperatura quanto da resistência.

Mudança da antena do gateway para aumentar o alcance.

Diminuir mais o consumo do MCU em modo de economia de energia.

Adicionar outros sensores, como de pH e nutrientes.

Escrever um software que permita visualizar os valores em um mapa.

• Desenvolvimento de um dispositivo capaz de medir grandezas importantes para a agricultura. • Integrado em uma só PCB. • Custo baixo. • Alta vida da bateria. • Longo alcance; Lado Dispositivo:; • Desenvolvimento de um gateway capaz de tratar os dados recebidos de vários dispositivos. • Armazenamento das informações em um banco de dados SQLite • Disponibilizar o acesso ao banco de dados na rede local, com interface web PHPLiteAdmin; Lado Gateway:

### Solução de baixo custo ( R$ 25 )

### Alcance de 1,4 km

Autonomia de um ano e quatro meses.

### Relevante para a realidade brasileira

### Gateway desenvolvido com o processamento dos sinais e armazendamento num banco de dados

SQLite.

# 8. Conclusão

# 9. Bibliografia

LIMA, J. NASA confirma dados da Embrapa sobre área plantada no Brasil. EMBRAPA. 2017. Disponível em: <https://www.embrapa.br/busca-de-noticias/-/noticia/30972114/nasa-confirma-dados-da-embrapa-sobre-area-plantada-no-brasil>. Acesso em: 03/10/2018.

EMBRAPA. Soja em números (safra 2017/2018) . EMBRAPA .2018 .Disponível em: <https://www.embrapa.br/web/portal/soja/cultivos/soja1/dados-economicos>. Acesso em: 03/10/2018.

FONTES, H. Agricultura 4.0 conecta o campo. 2017. Disponível em: <https://www.unicamp.br/unicamp/ju/noticias/2017/09/21/agricultura-40-conecta-o-campo>. Acesso em: 03/10/2018.

PAPP, A. Agricultura de precisão ganha espaço no país 2014. Disponível em: <https://exame.abril.com.br/economia/agricultura-de-precisao-ganha-espaco-no-pais/>. Acesso em: 03/10/2018.

MIZUGUCHI J. et al. Fringing Field Capacitive Sensor for Measuring Soil Water Content: Design, Manufacture, and Testing,IEEE Transactions on Instrumentation and Measurement, vol. 64, no. 1, pp. 212-220, Jan. 2015. doi: 10.1109/TIM.2014

DEAN, R. N. et al. A capacitive fringing field sensor design for moisture measurementbased on printed circuit board technology.IEEE Transactions on Instrumentation andMeasurement, v. 61, n. 4, p. 1105–1112, April 2012.

CASALS, L. et al. Modeling the Energy Performance of LoRaWAN. Sensors (2017).
AMETHERM. NTC Thermistor Beta. Disponível em <https://www.ametherm.com/thermistor/ntc-thermistor-beta>. Acesso em 01/12/2018

Obrigado pela atenção.

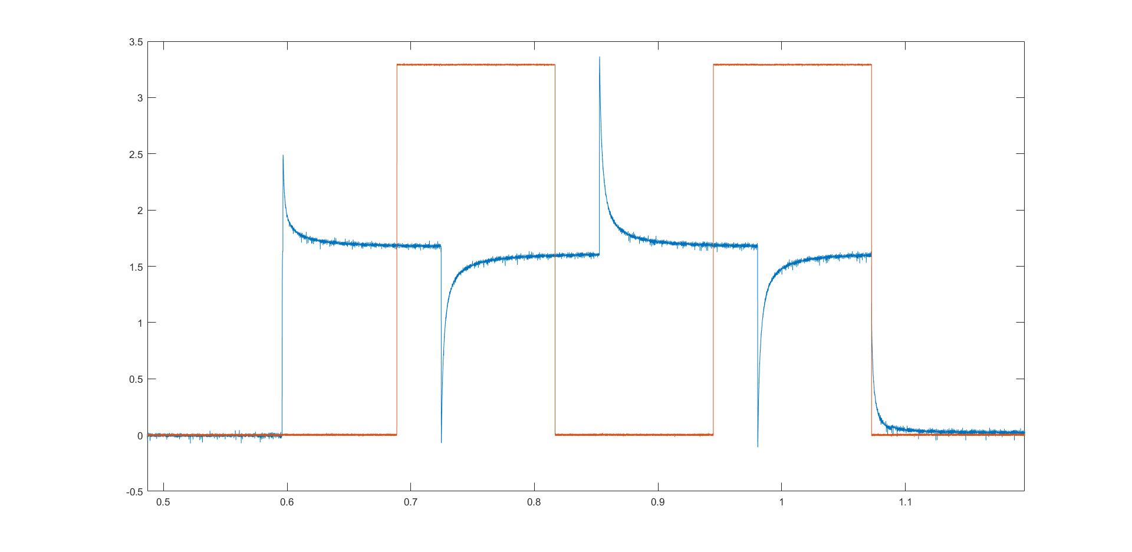
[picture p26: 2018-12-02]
1_Simulations/HR202/Images/adc_sample_with_hr202_os16_peaks3_5.jpg

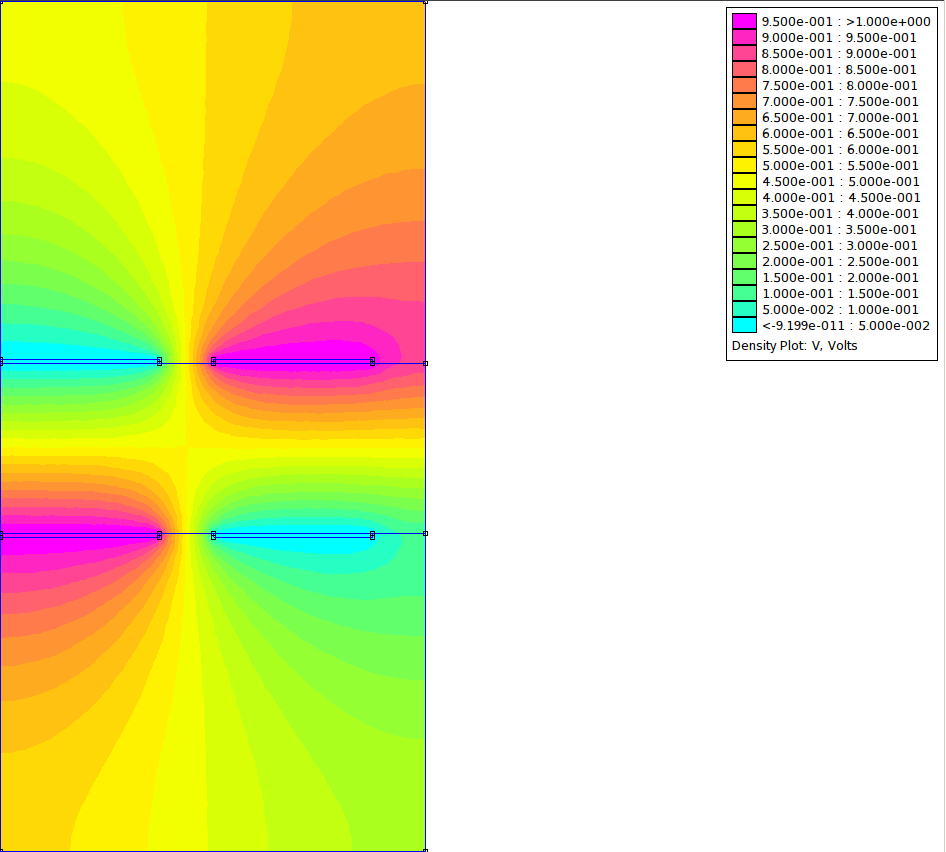
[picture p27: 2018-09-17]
1_Simulations/Moisture sensor/Simulation/FEMM Files/Images/w15_d05_soil.png

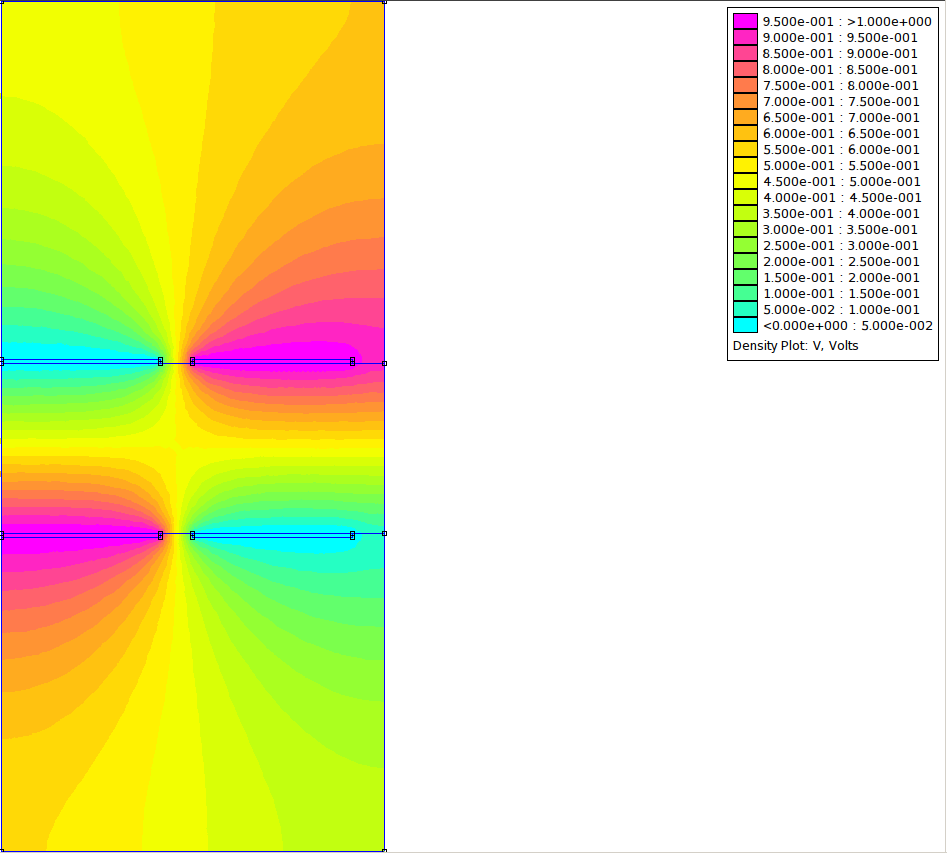
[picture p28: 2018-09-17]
1_Simulations/Moisture sensor/Simulation/FEMM Files/Images/w15_d03_soil.png

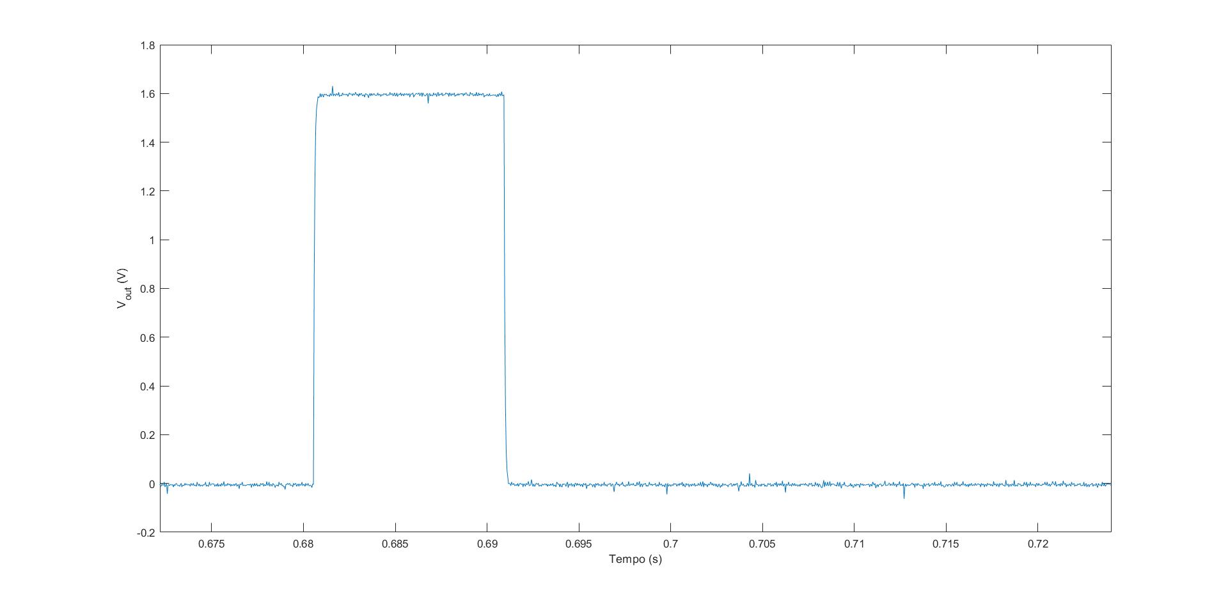
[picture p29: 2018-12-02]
1_Simulations/NTC/Images/out_10ms.jpg

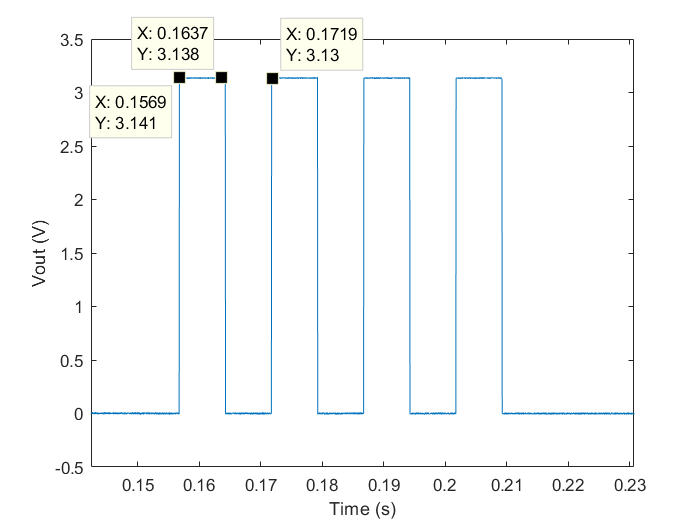
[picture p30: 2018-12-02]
1_Simulations/Moisture sensor/Images/sqwave_pulses.png

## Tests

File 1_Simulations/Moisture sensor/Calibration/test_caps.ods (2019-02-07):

Capacitor | Counts | Capacitance | Count | C (F)
open | 30040 | 2,25721661605752E-08 | 0 | 0
2,2p | 30042 | 2,25736689679095E-08 | 2 | 1,50280733425934E-12 | 1.5p
5p | 30045 | 2,25759231789109E-08 | 5 | 3,75701833564834E-12 | 3.75p
15p | 30060 | 2,25871942339178E-08 | 20 | 1,50280733425934E-11 | 15p
220p | 30333 | 2,27923274350442E-08 | 293 | 2,20161274468993E-10 | 220p
470p | 30669 | 2,30447990671998E-08 | 629 | 4,72632906624562E-10 | 472p
1,3n | 31382 | 2,35805498818633E-08 | 1342 | 1,00838372128802E-09 | 1n
10,6n | 42985 | 3,22990866315688E-08 | 12945 | 9,72692047099356E-09 | 9.72n
sensor open | 30192 | 2,2686379517979E-08 | 152 | 1,1421335740371E-10 | 114p
sensor with hand over it | 30240 | 2,27224468940012E-08 | 200 | 1,50280733425934E-10 | 150p
 |  |  | Here we subtract the open capacitance
 | Capacitor | Count | C (F)
 | Open | 0 | 0
 | 2,2p | 2 | 1,50280733425934E-12
 | 5p | 5 | 3,75701833564834E-12
 | 15p | 20 | 1,50280733425934E-11
 | 220p | 293 | 2,20161274468993E-10
 | 470p | 629 | 4,72632906624562E-10
 | 1 n | 1342 | 1,00838372128802E-09
 | 10 n | 12945 | 9,72692047099356E-09

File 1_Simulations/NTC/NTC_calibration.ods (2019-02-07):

T ( C ) | T (K) | R (Ohms) | B (K)
0 | 273,15 | 31570 | 3747,96017639995
20 | 293,15 | 12380 | 4153,69034491052
82,1 | 355,25 | 1040 | 4033,91475238639
 |  | Média | 3978,52175789895
T ( C ) | Erro ( C )
0 | 1,65
20 | 0,52
82,1 | -5,47

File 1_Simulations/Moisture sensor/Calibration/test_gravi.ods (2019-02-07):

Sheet: Sheet1
Sample | T1 | T2 | T3 | Water
Mr (g) | 4 | 5 | 6 | - | Mr | Recipient’s mass
Mm (g) | 24 | 29 | 29 | - | Mm | Mass before oven
Ms (g) | 18 | 20 | 20 | - | Ms | Mass after oven
Cont | 935 | 1248 | 1578 | 2313 | Cont value not connected to anything: | 30134
C (pF) | 702,56242876624 | 937,751776577826 | 1185,71498673062 | 1737,99668207092
MS | 42,8571428571429 | 60 | 64,2857142857143 | 101,694229922417
 |  |  |  |  |  |  | 0,058512326848198 | 0
 |  |  |  |  |  |  | 0,003154791477553 | #N/A
 |  |  |  |  |  |  | 0,994219586716569 | 5,25904060137831
 |  |  |  |  |  |  | 343,996021726147 | 2
 |  |  |  |  |  |  | 9514,07273900815 | 55,315016093891

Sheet: Sheet2
x | 42,2 | 46,715
f(x) | 66 | 75
42,2 | 46,715
66 | 75

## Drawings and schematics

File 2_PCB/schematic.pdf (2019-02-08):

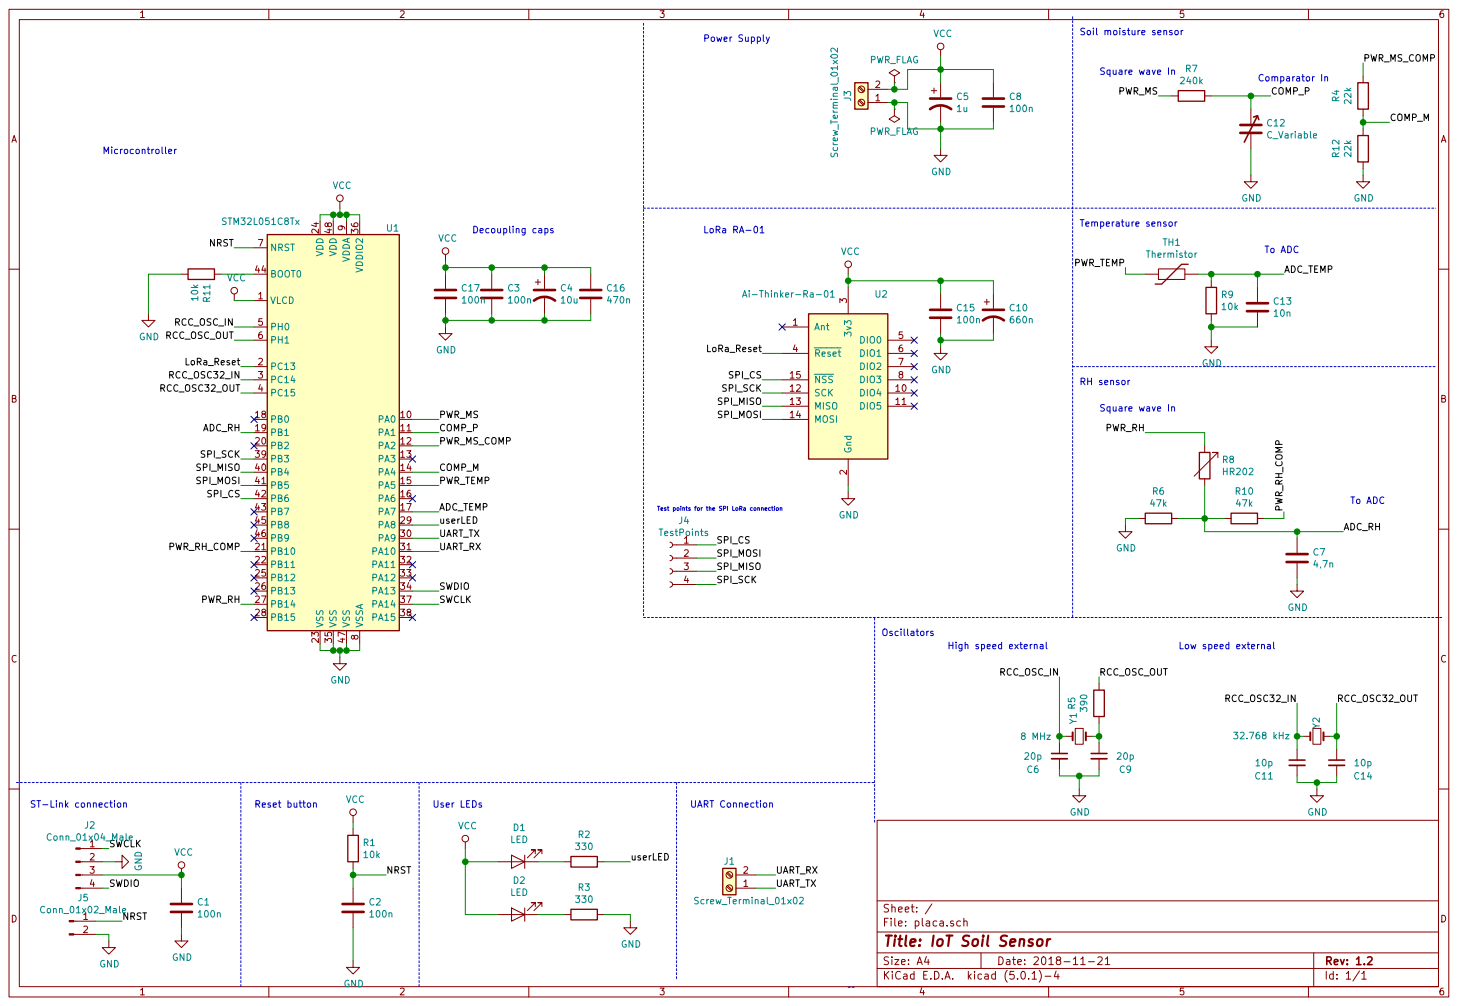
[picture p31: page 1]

LoRa RA-01 Microcontroller GND

9 VDDIO2 36 VLCD 1 VSS 23 VSS 35 VSS 47 VSSA

3 Reset 4 DIO0 5 DIO1 6 DIO2 7 DIO3 8 Ai-Thinker-Ra-01 U2 GND

File: placa.sch Sheet: /
Id: 1/1 Title: IoT Soil Sensor

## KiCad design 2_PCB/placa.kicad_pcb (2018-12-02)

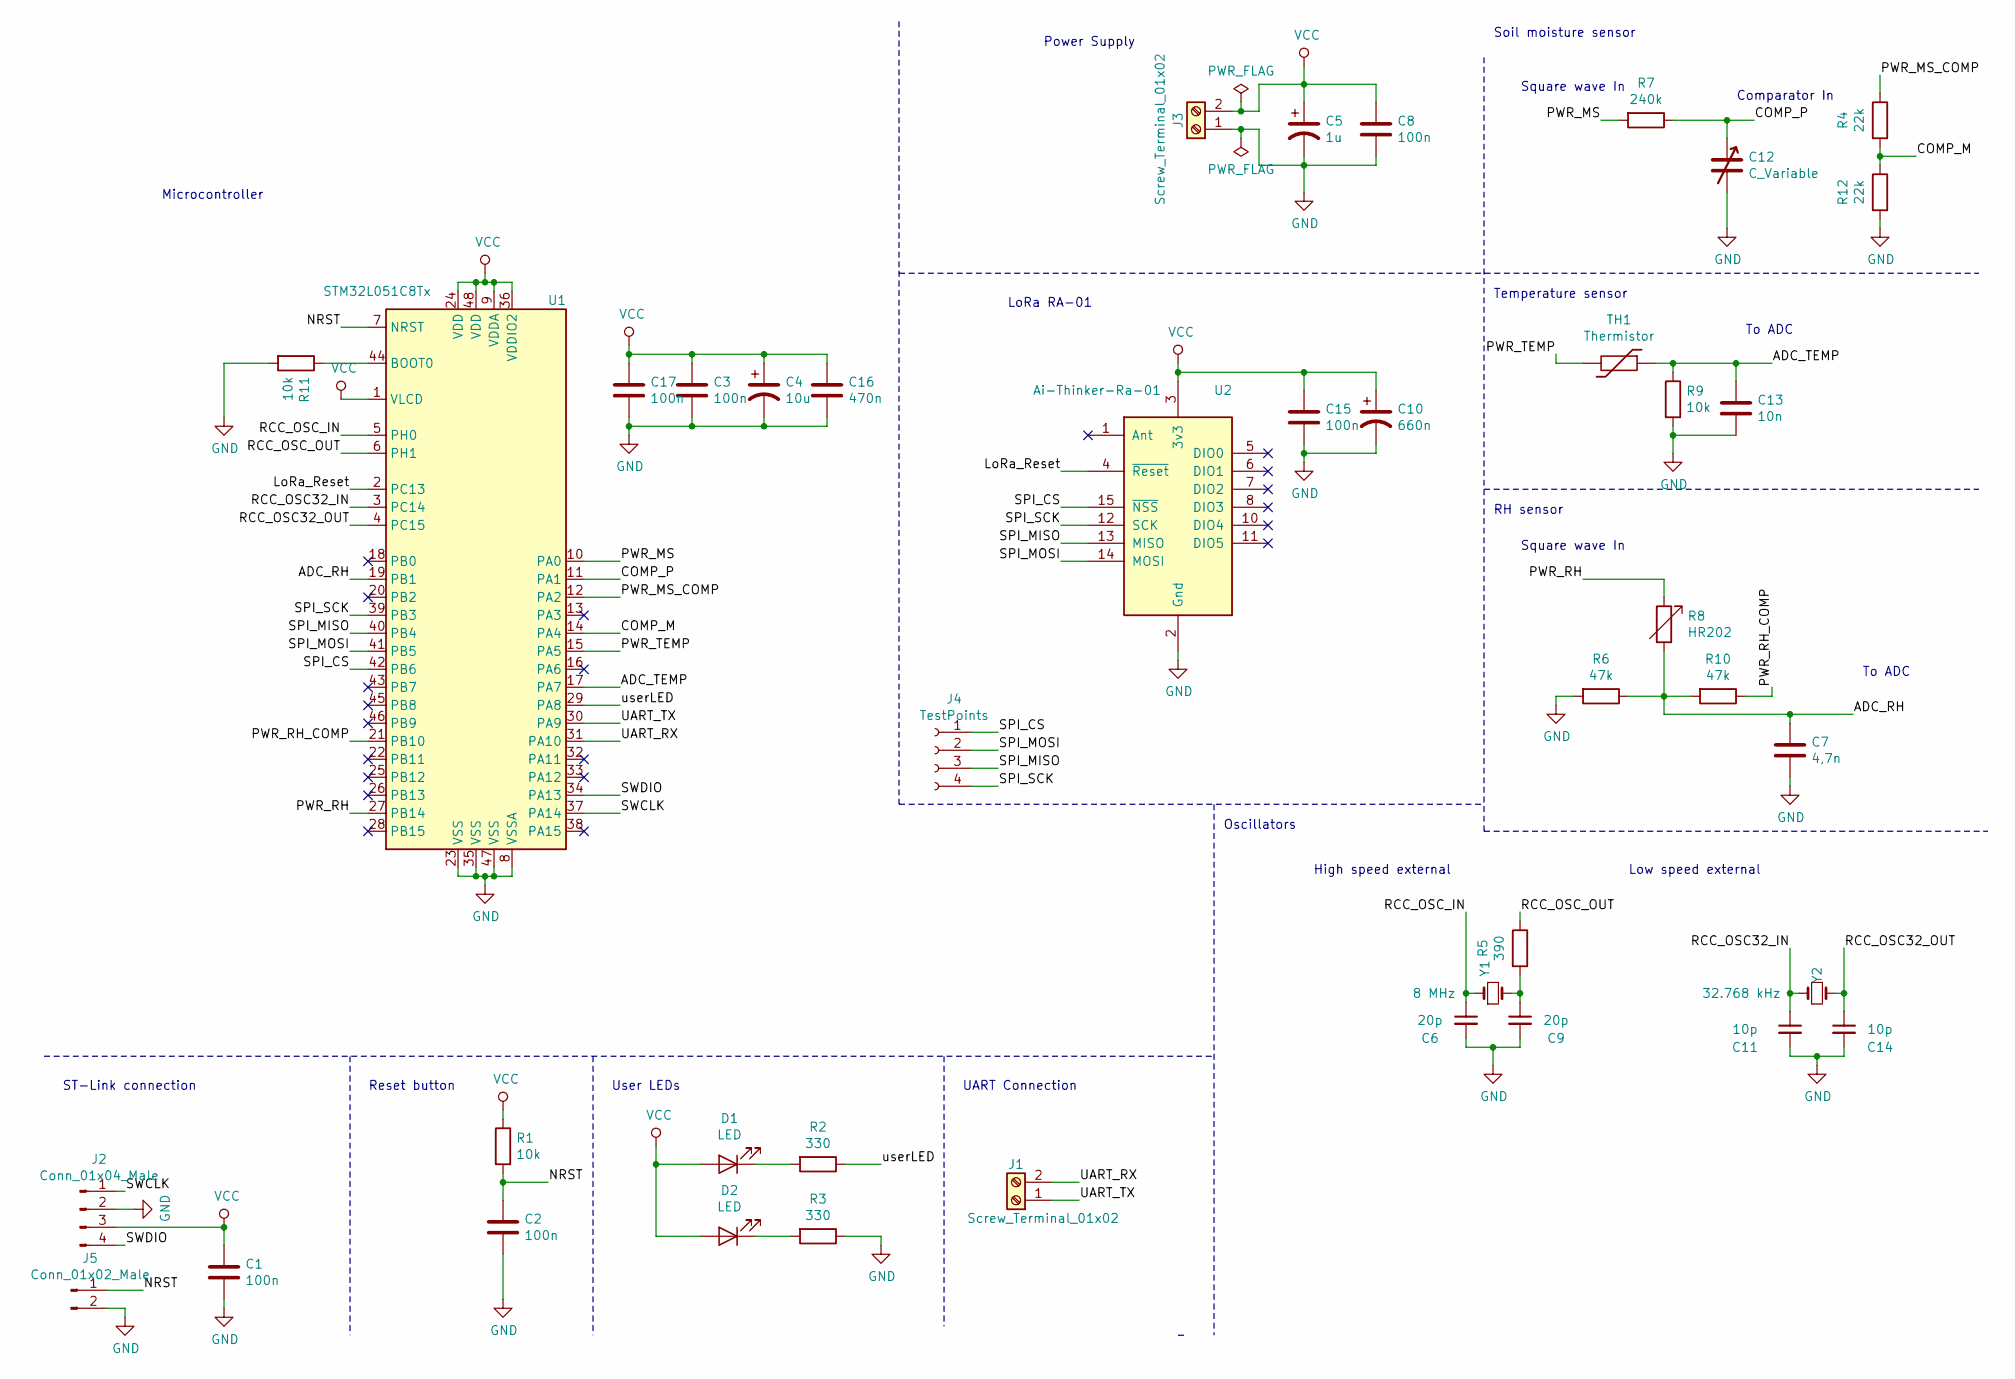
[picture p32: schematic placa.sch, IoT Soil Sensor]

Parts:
C1, C2, C3, C8, C15, C17: 100n; C_0805_2012Metric_Pad1.15x1.40mm_HandSolder
C4: 10u; CP_Radial_D5.0mm_P2.50mm
C5: 1u; CP_Radial_D5.0mm_P2.00mm
C6, C9: 20p; C_0805_2012Metric_Pad1.15x1.40mm_HandSolder
C7: 4,7n; C_0805_2012Metric_Pad1.15x1.40mm_HandSolder
C10: 660n; C_0805_2012Metric_Pad1.15x1.40mm_HandSolder
C11, C14: 10p; C_0805_2012Metric_Pad1.15x1.40mm_HandSolder
C12: C_Variable; Moisture Sensor
C13: 10n; C_0805_2012Metric_Pad1.15x1.40mm_HandSolder
C16: 470n; C_0805_2012Metric_Pad1.15x1.40mm_HandSolder
D1, D2: LED; LED_0805_2012Metric_Pad1.15x1.40mm_HandSolder
J1, J3: Screw_Terminal_01x02; PinHeader_1x02_P2.54mm_Vertical
J2: Conn_01x04_Male; PinHeader_1x04_P2.54mm_Vertical
J4: TestPoints; PinHeader_1x04_P2.54mm_Vertical
J5: Conn_01x02_Male; PinHeader_1x02_P2.54mm_Vertical
R1, R9, R11: 10k; R_0805_2012Metric_Pad1.15x1.40mm_HandSolder
R2, R3: 330; R_0805_2012Metric_Pad1.15x1.40mm_HandSolder
R4, R12: 22k; R_0805_2012Metric_Pad1.15x1.40mm_HandSolder
R5: 390; R_0805_2012Metric_Pad1.15x1.40mm_HandSolder
R6, R10: 47k; R_0805_2012Metric_Pad1.15x1.40mm_HandSolder
R7: 240k; R_0805_2012Metric_Pad1.15x1.40mm_HandSolder
R8: HR202; R_Axial_DIN0204_L3.6mm_D1.6mm_P1.90mm_Vertical
TH1: Thermistor; R_Axial_DIN0204_L3.6mm_D1.6mm_P1.90mm_Vertical
U1: STM32L051C8Tx; LQFP-48_7x7mm_P0.5mm
U2: Ai-Thinker-Ra-01; Ai-Thinker-Ra-01-LoRa
Y1: 8 MHz; Crystal_HC49-U_Vertical
Y2: 32.768 kHz; Crystal_Round_D1.0mm_Vertical

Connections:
/ADC_RH: C7.1, R6.1, R8.2, R10.2, U1.19 (PB1)
/ADC_TEMP: C13.1, R9.1, TH1.1, U1.17 (PA7)
/COMP_M: R4.2, R12.1, U1.14 (PA4)
/COMP_P: C12.1, R7.1, U1.11 (PA1)
/LoRa_Reset: U1.2 (PC13), U2.4 (~Reset)
/NRST: C2.1, J5.1, R1.2, U1.7 (NRST)
/PWR_MS: R7.2, U1.10 (PA0)
/PWR_MS_COMP: R4.1, U1.12 (PA2)
/PWR_RH: R8.1, U1.27 (PB14)
/PWR_RH_COMP: R10.1, U1.21 (PB10)
/PWR_TEMP: TH1.2, U1.15 (PA5)
/RCC_OSC32_IN: C11.1, U1.3 (PC14), Y2.2
/RCC_OSC32_OUT: C14.1, U1.4 (PC15), Y2.1
/RCC_OSC_IN: C6.1, U1.5 (PH0), Y1.1
/RCC_OSC_OUT: R5.1, U1.6 (PH1)
/SPI_CS: J4.1, U1.42 (PB6), U2.15 (~NSS)
/SPI_MISO: J4.3, U1.40 (PB4), U2.13 (MISO)
/SPI_MOSI: J4.2, U1.41 (PB5), U2.14 (MOSI)
/SPI_SCK: J4.4, U1.39 (PB3), U2.12 (SCK)
/SWCLK: J2.1, U1.37 (PA14)
/SWDIO: J2.4, U1.34 (PA13)
/UART_RX: J1.2, U1.31 (PA10)
/UART_TX: J1.1, U1.30 (PA9)
/userLED: R2.1, U1.29 (PA8)
GND: C1.2, C2.2, C3.2, C4.2, C5.2, C6.2, C7.2, C8.2, C9.2, C10.2, C11.2, C12.2, C13.2, C14.2, C15.2, C16.2, C17.2, J2.2, J3.1, J5.2, R3.1, R6.2, R9.2, R11.2, R12.2, U1.8 (VSSA), U1.23 (VSS), U1.35 (VSS), U1.47 (VSS), U2.2 (Gnd), U2.9 (Gnd), U2.16 (Gnd)
unnamed: C9.1, R5.2, Y1.2
unnamed: D1.1 (K), R2.2
unnamed: D2.1 (K), R3.2
unnamed: R11.1, U1.44 (BOOT0)
VCC: C1.1, C3.1, C4.1, C5.1, C8.1, C10.1, C15.1, C16.1, C17.1, D1.2 (A), D2.2 (A), J2.3, J3.2, R1.1, U1.1 (VLCD), U1.9 (VDDA), U1.24 (VDD), U1.36 (VDDIO2), U1.48 (VDD), U2.3 (3v3)

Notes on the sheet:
Square wave In
Comparator In
Soil moisture sensor
Temperature sensor
RH sensor
To ADC
Power Supply
ST-Link connection
Reset button
User LEDs
Oscillators
High speed external
Low speed external
UART Connection
LoRa RA-01
Microcontroller

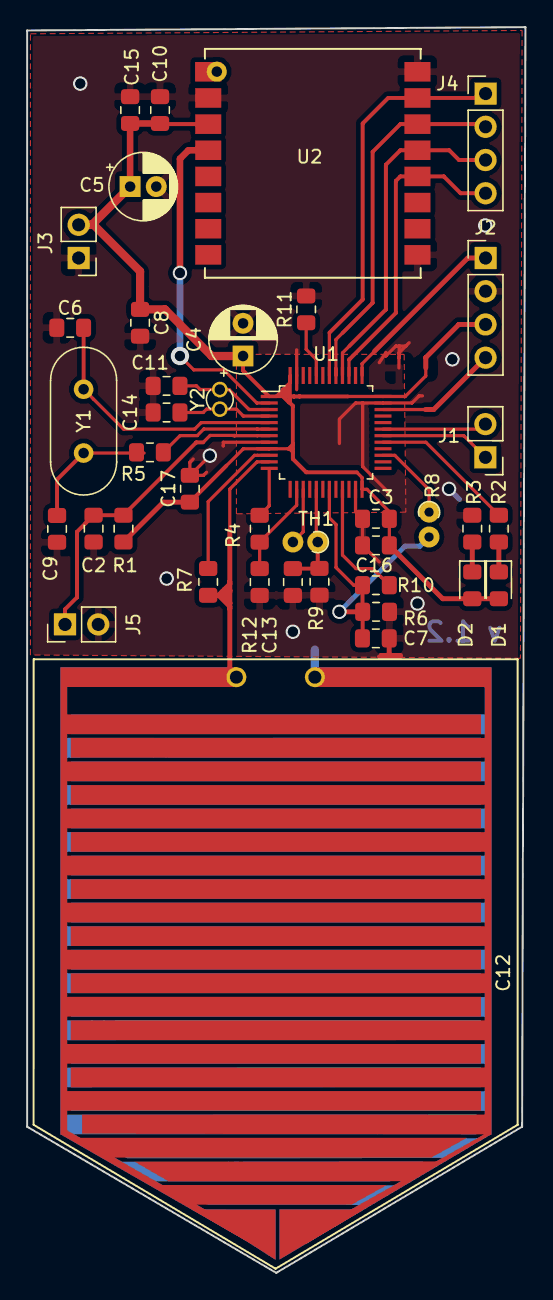
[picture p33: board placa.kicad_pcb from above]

Board: 2 copper layers, 38.1 x 95.2 mm, 40 parts (0 on the bottom side), 30 nets.

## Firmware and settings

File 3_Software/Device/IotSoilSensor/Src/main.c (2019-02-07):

/**
  ******************************************************************************
  * @file           : main.c
  * @brief          : Main program body
  ******************************************************************************
  ** This notice applies to any and all portions of this file
  * that are not between comment pairs USER CODE BEGIN and
  * USER CODE END. Other portions of this file, whether 
  * inserted by the user or by software development tools
  * are owned by their respective copyright owners.
  *
  * COPYRIGHT(c) 2018 STMicroelectronics
  *
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
  ******************************************************************************
  */
/* Includes ------------------------------------------------------------------*/
#include "main.h"
#include "stm32l0xx_hal.h"

/* USER CODE BEGIN Includes */
#include "NTC.h"
#include "HR202.h"
#include "SX1278.h"
#include "RA01.h"
#include "MoistureSensor.h"

/* USER CODE END Includes */

ADC_HandleTypeDef hadc;

COMP_HandleTypeDef hcomp1;

RTC_HandleTypeDef hrtc;

SPI_HandleTypeDef hspi1;

TIM_HandleTypeDef htim2;
TIM_HandleTypeDef htim21;
TIM_HandleTypeDef htim22;

/* USER CODE BEGIN PV */

/* USER CODE END PV */

void SystemClock_Config(void);
static void MX_GPIO_Init(void);
static void MX_SPI1_Init(void);
static void MX_COMP1_Init(void);
static void MX_ADC_Init(void);
static void MX_TIM21_Init(void);
static void MX_TIM2_Init(void);
static void MX_TIM22_Init(void);
static void MX_RTC_Init(void);

void HAL_TIM_MspPostInit(TIM_HandleTypeDef *htim);
                                
                                

/* USER CODE BEGIN PFP */

/* USER CODE END PFP */

/**
  * @brief  The application entry point.
  *
  * @retval None
  */
int main(void)
{
  /* MCU Configuration----------------------------------------------------------*/

  /* Reset of all peripherals, Initializes the Flash interface and the Systick. */
  HAL_Init();

  /* Configure the system clock */
  SystemClock_Config();

  /* Initialize all configured peripherals */
  MX_GPIO_Init();
  MX_SPI1_Init();
  MX_COMP1_Init();
  MX_ADC_Init();
  MX_TIM21_Init();
  MX_TIM2_Init();
  MX_TIM22_Init();
  MX_RTC_Init();
  /* USER CODE BEGIN 2 */

  // Init All
  ADC_calibrate();
  MS_init();
  NTC_init();
  HR202_init();

  SX1278_t LoRa;
  SX1278_hw_t LoRaHW;
  LoRa_init(&LoRa, &LoRaHW);

  uint16_t message_nb = 0;

  /* USER CODE END 2 */

  /* Infinite loop */
  /* USER CODE BEGIN WHILE */
  while (1)
  {
	    GPIO_userLed_on();

	    // variable containing the payload
		uint8_t txsend[PAYLOAD_SIZE];
		uint32_t rh_value, temperature_value, MS_value;

		// Get values from sensors
		temperature_value = NTC_getTemp();
		MS_value = MS_getMS();
		rh_value = HR202_getRH();

		// Sort values into bytes in order to send them
		LoRa_parsePayload(txsend, temperature_value, MS_value, rh_value, message_nb);

		// Send data via Lora
		SX1278_LoRaEntryTx(&LoRa, PAYLOAD_SIZE, 2000);
		SX1278_LoRaTxPacket(&LoRa, (uint8_t *) txsend, PAYLOAD_SIZE, 2000);

		// Put LoRa module to sleep
		SX1278_sleep(&LoRa);

		// Increment message nb
		message_nb++;

	    GPIO_userLed_off();

		// get into stop mode
	    SCB->SCR |= SCB_SCR_SLEEPDEEP_Msk; // low-power mode = stop mode
		PWR->CR &= ~PWR_CR_PDDS;
		PWR->CSR &= ~(PWR_CSR_WUF);

		// Select MSI as stop clock
		RCC->CFGR &= ~(RCC_CFGR_STOPWUCK);

		__WFI();

  /* USER CODE END WHILE */

  /* USER CODE BEGIN 3 */

  }
  /* USER CODE END 3 */

}

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
/* USER CODE BEGIN 4 */


void HAL_RTC_AlarmAEventCallback(RTC_HandleTypeDef *hrtc)
{

}


/* USER CODE END 4 */
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


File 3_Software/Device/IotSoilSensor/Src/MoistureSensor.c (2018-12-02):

#include "MoistureSensor.h"
#include "GPIO.h"
#include "stm32l0xx_hal.h"
#include "COMP.h"

#define COMP_MEASURES	(8)

void MS_init()
{
	// Turn timer off
	timer_MS_init();

	// Turn comp off
	COMP_init();
}

uint32_t MS_getMS()
{
	uint32_t countValue = 0;

	// Turn on bridge
	GPIO_MS_on();

	// Turn on Comp
	COMP_start();

	// Reset timer
	timer_MS_reset();

	// Start square wave
	timer_MS_start_square();

	uint32_t lastCompValue = COMP_getOutput();

	for (uint32_t i=0; i<COMP_MEASURES; i++)
	{
		// poll comparator
		while ( lastCompValue == COMP_getOutput() ) {
		}

		// Save timer count
		countValue += timer_MS_getTimer();
		// Save current state
		lastCompValue = COMP_getOutput();
	}
	// Turn off square
	timer_MS_stop_square();

	// Turn off bridge
	GPIO_MS_off();

	GPIO_MS_timer_off();

	countValue = countValue/COMP_MEASURES;

	return countValue;
}

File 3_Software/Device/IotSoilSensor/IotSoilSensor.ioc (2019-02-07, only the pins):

Mcu.UserName=STM32L051C8Tx
PA0.GPIO_Label=PWR_MS
PA0.Signal=S_TIM2_CH1
PA1.Signal=COMP1_INP
PA13.Signal=SYS_SWDIO
PA14.Signal=SYS_SWCLK
PA2.GPIO_Label=PWR_MS_COMP
PA2.Signal=GPIO_Output
PA4.Signal=COMP1_INM
PA5.GPIO_Label=PWR_Temp
PA5.Signal=GPIO_Output
PA7.GPIO_Label=ADC_TEMP
PA7.Signal=ADC_IN7
PA8.GPIO_Label=userLED
PA8.Signal=GPIO_Output
PA9.Signal=GPIO_Output
PB1.GPIO_Label=ADC_RH
PB1.Signal=ADC_IN9
PB10.GPIO_Label=PWR_RH_COMP
PB10.Signal=GPIO_Output
PB14.GPIO_Label=PWR_RH
PB14.Signal=S_TIM21_CH2
PB3.Signal=SPI1_SCK
PB4.Signal=SPI1_MISO
PB5.Signal=SPI1_MOSI
PB6.GPIO_Label=LoRa_SS
PB6.Signal=GPIO_Output
PC13.GPIO_Label=LoRa_Reset
PC13.Signal=GPIO_Output
PH0-OSC_IN.Signal=RCC_OSC_IN
PH1-OSC_OUT.Signal=RCC_OSC_OUT

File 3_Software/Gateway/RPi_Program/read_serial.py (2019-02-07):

import serial
import sqlite3
import numpy as np
from scipy.interpolate import interp1d

# Relative humidity values list
rh_vals={0:  [100e6, 100e6, 6.4e6, 2.9e6, 1.4e6, 700e3, 370e3, 190e3, 105e3, 62e3, 38e3  ,   23e3, 15.5e3, 10.5e3, 7.1e3],
        5:  [100e6, 10e6,   4.6e6, 2.1e6, 1.0e6, 500e3, 260e3, 140e3, 80e3,  48e3, 30e3  ,   18e3, 12e3  , 8.2e3 , 5.3e3],
        10: [100e6, 7e6,    3.2e6, 1.5e6, 750e3, 380e3, 200e3, 110e3, 62e3,  37e3, 24e3  ,   15e3, 10e3  , 6.8e3 , 4.7e3],
        15: [10e6,   5e6,    2.3e6, 1.1e6, 540e3, 280e3, 150e3, 84e3 , 50e3,  30e3, 19e3  ,   12e3, 8e3   , 5.5e3 , 4.0e3],
        20: [6.7e6,  3.4e6,  1.75e6,850e3, 420e3, 210e3, 115e3, 64e3 , 39e3,  24e3, 15.5e3,   10e3, 7e3   , 4.8e3 , 3.3e3],
        25: [5e6,    2.6e6,  1.3e6, 630e3, 310e3, 160e3, 87e3,  49e3 , 31e3,19.5e3, 13e3  ,  8.4e3, 5.7e3 , 4e3,    2.8e3],
        30: [3.9e6,  1.9e6,  970e3, 460e3, 235e3, 125e3, 69e3,  39e3 , 25e3,  16e3,10.5e3 ,  7.2e3, 5.0e3 , 3.5e3,  2.5e3], 35: [3.0e6,  1.5e6,  740e3, 380e3, 190e3, 100e3, 56e3,  33e3, 20e3,   13e3, 9e3   ,  6.2e3, 4.3e3 , 3.1e3,  2.2e3], 40: [2.4e6,  1.1e6,  570e3, 280e3, 140e3, 78e3,  45e3,  27e3,17.5e3,11.5e3, 8e3   ,  5.6e3, 3.9e3 , 2.8e3,  2e3  ],
        45: [1.75e6, 880e3,  420e3, 210e3, 110e3, 64e3,  38e3,  24e3, 15e3,   10e3, 7e3   ,  4.9e3, 3.4e3 , 2.4e3,  1.8e3]     
       } 

# function for rounding to nearest five (for rounding temperature)
def round_nearest_5(x):
    return int( 5 * round(float(x)/5))

# Starts serial connection
ser = serial.Serial("/dev/ttyS0", 115200)

# Infinite loop. Should change to something more elegant in the future
while True:

    # Get data (10 bytes) from the serial port
    received_data = ser.read(10)
    
    # Print the received data
    print(received_data)

    # decode message data
    temp_b = ((received_data[0] << 4) + ((received_data[1] & 0x0f)))
    MS_b = ((received_data[2] << 8) + received_data[3])
    rh_b = ((received_data[4] << 16) + (received_data[5] << 8) + (received_data[6]))
    rhp_b = rh_b >> 12
    rhm_b = rh_b & 0xfff
    message_nb = ((received_data[7] << 6) + ((received_data[8] & 0xFC) >> 2))
    devid = (((received_data[8] & 0x03) << 8) + received_data[9])
    
    # decode brutes into real values

    # Temperature
    p = np.poly1d([161.36243645, -211.11332061,  177.88707646,  -31.2102803])
    temp = p(temp_b/4095)

    # MS

    ## Get capacitance in pF

    if (devid == 1):
        calib_factor = 30013 #22564
    elif (devid == 2):
        calib_factor = 30134


    MS_pf = (-1e12*(MS_b-calib_factor)/(8e6*np.log(0.5)*240e3))

    ## Translates from capacitance to % humidity. Depends on the sensor, hence the devid separation
    if (devid == 1):
        MS = MS_pf/2
    elif (devid == 2):
        MS = MS_pf*0.05851232

    # Air humidity
    rh_x = np.linspace(20,90,15)

    ## create interpolation function
    f = interp1d(rh_vals[round_nearest_5(temp)][::-1], rh_x[::-1])

    ## Get R_rh given the output
    adc_val = np.absolute(rhp_b-rhm_b)/4095
    R_rh = 47e3*(1-adc_val)/(2*adc_val)

    ## use the interpolation function and the resistor value to find RH
    try:
        if (devid == 1):
            rh = 2*f(R_rh) - 18.12
        elif (devid == 2):
            rh = f(R_rh)
    except:
        rh = 20


    # Connect to database
    conn = sqlite3.connect('sensordata.db')
    
    curs = conn.cursor()

    # Send info to both databases, both brutes and decoded values
    curs.execute("INSERT INTO sensorbrutes(temperature, air_humidity, soil_humidity, msg_nb, devid, currentdate) values({},{},{},{},{},CURRENT_TIMESTAMP)".format(temp_b, (rhp_b-rhm_b), MS_b,message_nb, devid))
    curs.execute("INSERT INTO sensorvals(temperature, air_humidity, soil_humidity, msg_nb, devid, currentdate) values({},{},{},{},{},CURRENT_TIMESTAMP)".format(temp, rh, MS,message_nb, devid ))

    # Commit and close database connection
    conn.commit() 
    conn.close()

    # Print in terminal
    print(MS_b)
    print(temp)
    print(MS)
    print(MS_pf)
    print(rhp_b)
    print(rhm_b)
    print(rh)
    print(message_nb)
    print(devid)

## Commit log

2018-09-11 Updated some sensor values; Finished choice of components; Placements of components in PCB
    [placa.sch]
2018-09-13 Remap SPI pins, reposition components; start routing
    [placa.kicad_pcb, placa.sch]
2018-09-13 Finished first iteration of PCB
    [placa.kicad_pcb, placa.sch]
2018-09-17 Created and added capacitive sensor to PCB; Minor changes to the design
    [fringe_parameters_study.ods, placa.kicad_pcb, placa.sch]
2018-09-24 Got LaTeX doc working according to ABNT. Uploaded simulation files of the moisture sensor capacitor. Small changes to the board
    [placa.kicad_pcb, placa.sch]
2018-09-28 Version 1.01 of PCB (easier for home etch). Chapter one of document
    [placa.kicad_pcb]
2018-10-03 PCB version 1.1: Easier to home etch and added a BOOT0 PD resistor
    [BOM.csv, placa.kicad_pcb, placa.sch]
2018-10-16 New branch for new HW revision. To add different layout, comparator for MS, change in RH circ
    [av16_cap10n.csv, av16_nocap.csv, bare.csv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]
2018-10-19 started unit tests. PCB v1.2 routed
2018-10-26 tested NTC on target hardware. Updated NTC tests. Enabled ADC oversampling for NTC
2018-10-26 Adding new files
    [placa.kicad_pcb, placa.sch]
2018-11-06 Wrote HR202 app code and drivers, plus MS drivers and (most of) the code. Needs hardware testing. Adapted LoRa drivers, module answers but TX not tested
    [placa-B.Cu.gbr, placa-B.Mask.gbr, placa-B.SilkS.gbr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]
2018-12-02 Hardware tested all. MS, HR202, Temperature and LoRa module. Added code for the gateway
    [fringe_parameters_study.ods, placa.kicad_pcb, placa.sch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]
2019-02-07 Cleaned repo and organized it
    [BOM.csv, NTC_calibration.ods, av16_cap10n.csv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]
2019-02-08 Uploaded schematic pdf files
2019-02-08 few changes in schematic
    [placa.sch]

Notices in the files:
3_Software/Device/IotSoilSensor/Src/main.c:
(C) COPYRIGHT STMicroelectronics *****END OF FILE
